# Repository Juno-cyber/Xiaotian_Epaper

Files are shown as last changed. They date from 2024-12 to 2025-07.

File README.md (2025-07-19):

# xiaotian_Epaper

**一款语音控制的墨水屏桌面助手**

**具备时间显示、倒计时事件显示、累积事件显示、语音控制功能**

**一款动动嘴就能交互的极简风桌面摆件！**

**组成：** 墨水屏、stm32、vc02语音模块、实时时钟

**使用软件：** cubeide1.16.1、lceda专业版、solidworks2024、keyshot2024

**<font color='RedOrange'>完整资料：</font>** **已上传**github-[Xiaotian_Epaper](https://github.com/Juno-cyber/Xiaotian_Epaper)，gitee-[Xiaotian_Epaper](https://gitee.com/Juno-cyber/Xiaotian_Epaper)，oshwhub-[电路设计](https://oshwhub.com/juno_eda/xiaoshi_epaper)

**<font color='RedOrange'>视频：</font>**[[开源]墨水屏桌面备忘录！](https://www.bilibili.com/video/BV1hEdBY6EPM/?vd_source=bac4ee29cb575aa9bf0947bee030705f)

**<font color='RedOrange'>BOM清单：</font>**`1.Hadware\BOM清单2024-12-14.xlsx`

**<font color='RedOrange'>更新日志：</font>** 

1. 2025.5.16：解决了偶然出现的秒计时超出60导致计时停止问题，优化了时间自动更新（若编译时间超前当前时间或当前时间大于编译时间20年则更新为编译时间）
1. 2025.4.13：添加scene3红黑显示demo，为”时间时加一“添加边界限制；更新了3D结构文件，删除了需要内嵌螺母的我外壳版本；pcb完善了丝印；
1. 2025.2.11：首次烧录时根据系统编译时间自动更新时钟芯片时间
1. 2025.1.18：更新bom表中黑白红墨水屏器件链接，更新程序，添加二次开发教程
1. 2025.1.5：添加pcb焊接建议，bom表中增加了我使用的下载器购买链接
1. 2024.12.28：添加黑白红墨水屏供选择，版本v0.0.2
1. 2024.12.13：首次上传，版本v0.0.1

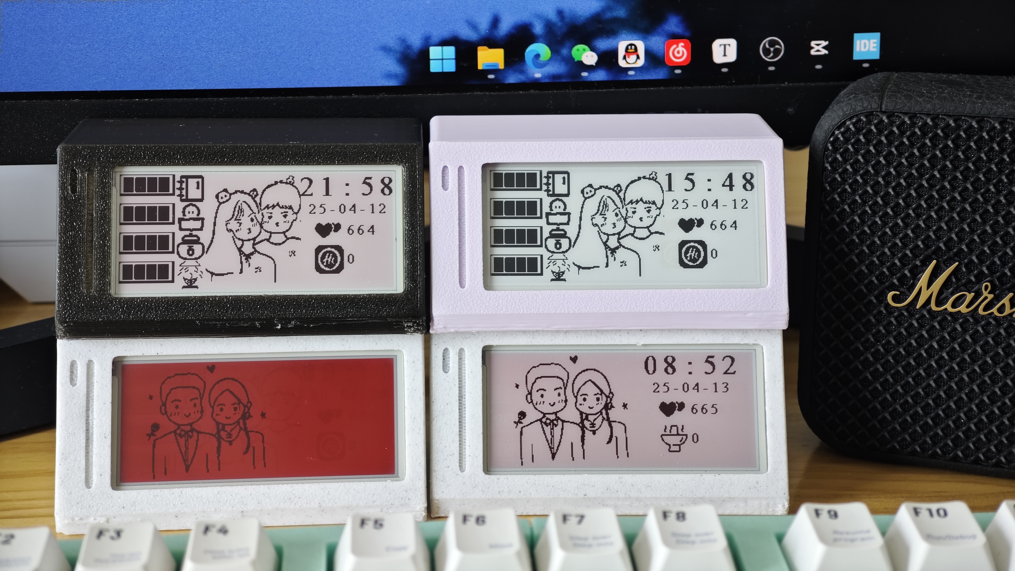
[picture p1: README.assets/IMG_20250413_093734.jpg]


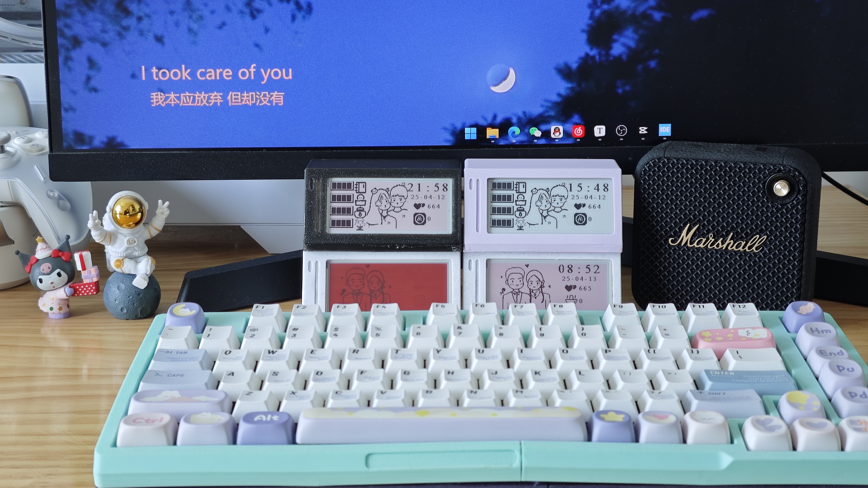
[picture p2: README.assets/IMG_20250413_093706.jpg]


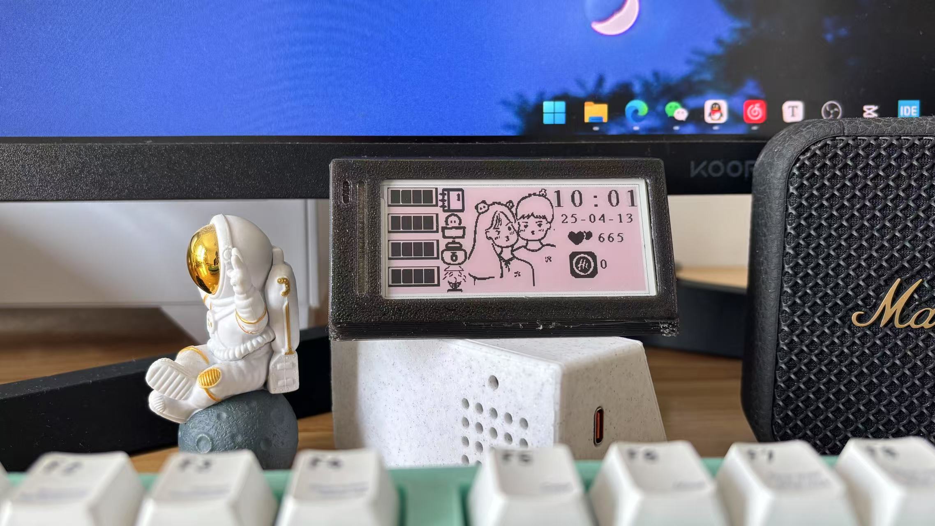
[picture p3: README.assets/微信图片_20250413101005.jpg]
微信图片_20250413101005


| 序号 | 文件名 | 描述 |
| ---- | --- | --- |
| 1 | Hardware | 硬件设计，BOM清单 |
| 2 | Firmware | 固件文件 |
| 3 | Software | 软件程序 |
| 4 | CAD_Model | 模型文件 |
| 5 | Docs | 文档 |
| 6 | Tools | 附带工具 |
| 7 | img | 输出图片 |
| 8 | REDME.assets | REDME中的图片 |

## 控制指令

**语音控制指令集**

| 命令词 | 回复语 | 备注 |
| --- | --- | --- |
| 请介绍你自己 | 你好我叫小天 我是一个桌面助手<br /> 你可以通过语音和我进行交互<br /> 你可以说浇过花了 浇过水了 更改时间 更换图片<br /> 有什么需要尽管给我说 | 需唤醒 |
| 你好小天\|小天小天 | 随时待命 | 唤醒词 |
| 写完日记了 | 记录每一天 | 需唤醒 |
| 看完书了 | 日拱一卒功不唐捐 | 需唤醒 |
| 加过水了 | 下次早点浇 | 需唤醒 |
| 坛子加过水了 | 美味需要时间酝酿 | 需唤醒 |
| 吃了海底捞 | 发工资了吗又吃海底捞 | 需唤醒 |
| 更改时间 | 想要调整时间你可以说时间年加一或者时间年减一 | 需唤醒 |
| 时间年加一 | | 需唤醒 |
| 时间年减一 | | 需唤醒 |
| 时间月加一 | | 需唤醒 |
| 时间月减一 | | 需唤醒 |
| 时间日加一 | | 需唤醒 |
| 时间日减一 | | 需唤醒 |
| 时间时加一 | | 需唤醒 |
| 时间时减一 | | 需唤醒 |
| 时间分加一 | | 需唤醒 |
| 时间分减一 | | 需唤醒 |
| 更换图片 | 已经更换照片 | 需唤醒 |

## 器件选型

**完整的bom清单在github和gitee工程中**：`Xiaotian_Epaper\1.Hadware\BOM清单2024-12-14.xlsx`

零件可在立创商城或者淘宝购买，哪里便宜在哪里买就好了

**墨水屏[Epaper](https://item.taobao.com/item.htm?id=520630517588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)：**

分辨率296x128像素 、2.9寸、黑白

刷新方式：全屏刷新/局部刷新（4灰阶不支持局刷）

刷新时间：全刷3秒，局刷0.6秒

据说无故障刷新次数为100w次，我设置每分钟刷新一次，那这样算，能够用两年，想想也还有点短

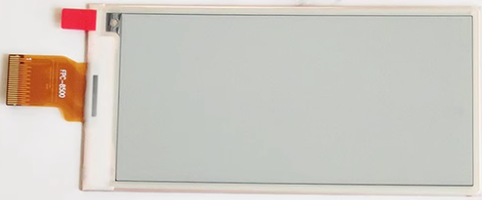
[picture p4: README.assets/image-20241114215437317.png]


**stm32f103cbt6**

72M主频，基本外设丰富，特别的是128k flash，对于当前所选墨水屏分辨率来说

一张全屏照片大小=296x128/8=4.7k，即使考虑到用上freeRTOS也可以无压力存20来张图像，并且往往无需全屏图像，对于个人开发来说完全够用了

**vc02语音模块**

一款低成本纯离线语音识别模组，**简单说就是写好对答语句，说特定语句执行特定功能**，这里使用时，说出特定语句发送串口指令到主控进行任务控制。支持150条本地指令离线识别，支持RTOS轻量级系统，具有丰富的外围接口，以及简单友好的[客制化工具](http://voice.ai-thinker.com/#/)，该项目放弃了按键交互，完全使用语音模块进行交互，**想干嘛动动嘴就行，君子动口不动手！**

**DS1302**

一款时钟芯片，用于离线时间记录，确保断电后设备仍然能保持时间

## 软件框架

使用cubeide经过初步封装后的freeRTOS，建立了四个任务init、show、run、read，分别执行初始化、显示、主要运行计算、读取任务

为了降低不同任务抢夺共享资源，用了两个无限时间等待的信号量确保run任务正常运行，用了两个事件组分别控制时钟芯片的数据读写和墨水屏的刷新显示

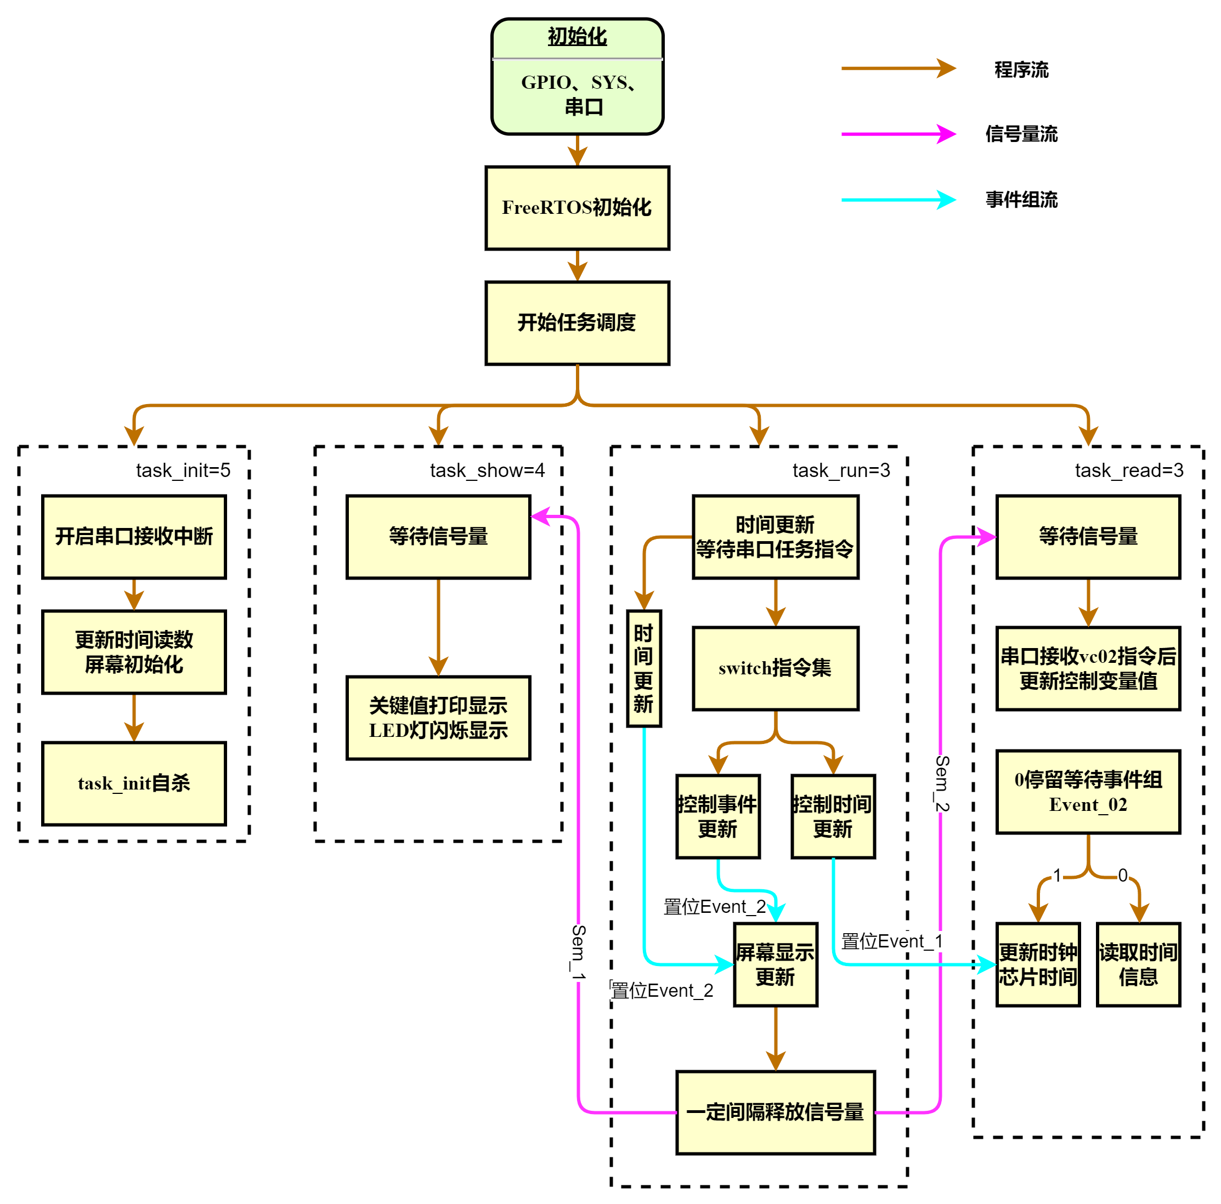
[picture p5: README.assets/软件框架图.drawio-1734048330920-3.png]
软件框架图.drawio


## 模块数据流

列出硬件组成中模块的电气连接及数据流向

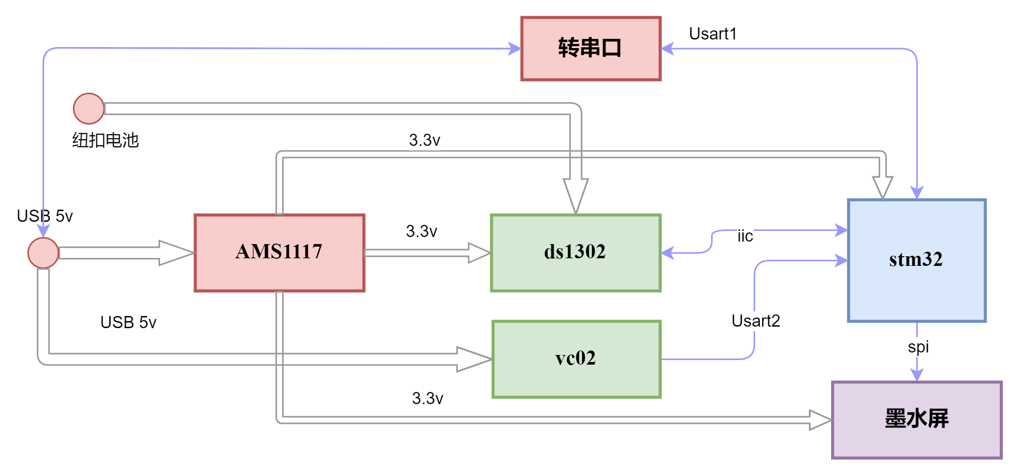
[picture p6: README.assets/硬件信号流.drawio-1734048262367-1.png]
硬件信号流.drawio


## 3D设计及安装

巧妙地外壳和屏幕壳体设计，使用Bambu的0.12mm打印刚好将屏幕壳体嵌入到外壳中，在底部使用两颗平头螺丝固定，表面外壳看不出什么安装的痕迹，对于审美的一点点强迫症，舒适了！

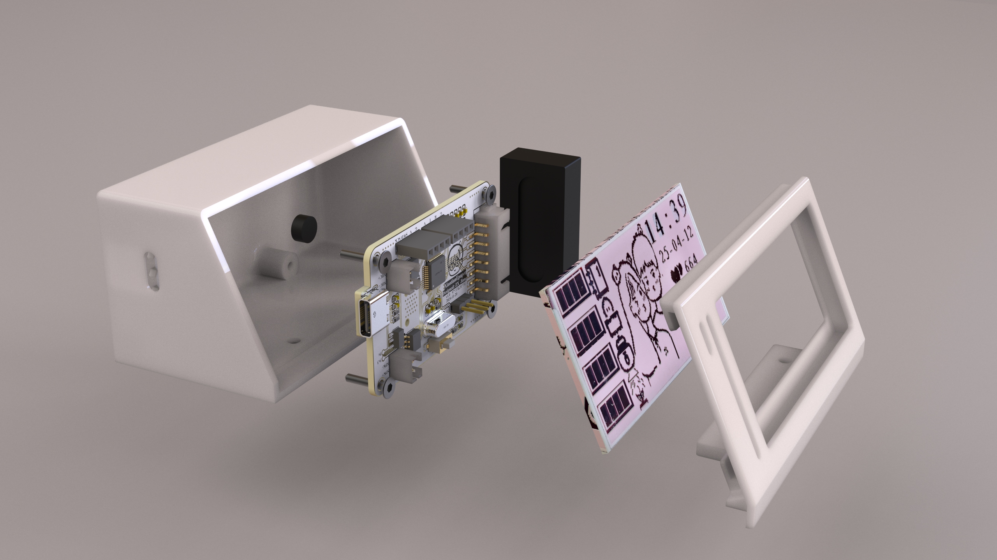
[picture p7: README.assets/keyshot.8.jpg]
keyshot.8


安装需要准备以下零件，选购链接已经在BOM表`Xiaotian_Epaper\1.Hadware\BOM清单2024-12-14.xlsx`中给出

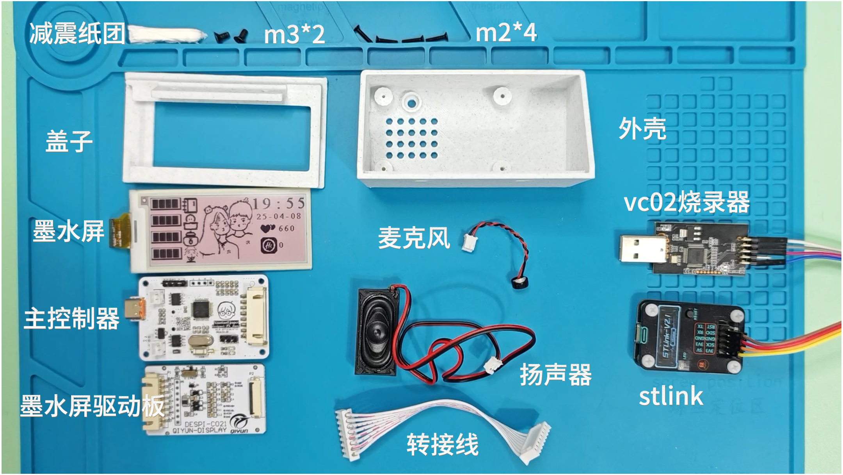
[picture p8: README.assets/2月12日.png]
2月12日


## PCB焊接建议

电容电阻使用的0603封装，需要用到**加热台**和**烙铁**，焊接不当需要拆除的话也需要用到**热风枪**，这里给一些手工焊接的建议，如果采用SMT焊接可以不用看

1. 手工焊接建议开钢网，当然想纯白嫖也可以不开，我没开也焊接成功了，就是难度稍微高一点
2. 首先用加热台焊接元器件最多的一面，但**注意不要一开始就把引脚密集的typeC和stm32主控芯片贴上去**，因为引脚过于密集，但凡锡膏多加一点就会短接，后续用烙铁不好分开，有的同学可能说用助焊剂容易分开，但我以前用的时候发现**助焊剂加热时间久了会导电短路**，有点恐怖。我实际发现比较好的方法是在加热台上等锡膏都融化了，用镊子把粘连的锡抚顺了，然后再放上typeC和stm32主控，成功率提高很多！
3. 焊接好了可以先连接typeC测试串口，能检测到串口一般说明最难的主控和typeC焊接没什么问题，有问题的话先检查用的线是不是只能充电没有信号线，确定是焊接问题，就需要用热风枪吹热拆下来然后再焊接了

**焊接成品如下**，手工抹的锡膏，表面会有一些锡球不那么美观

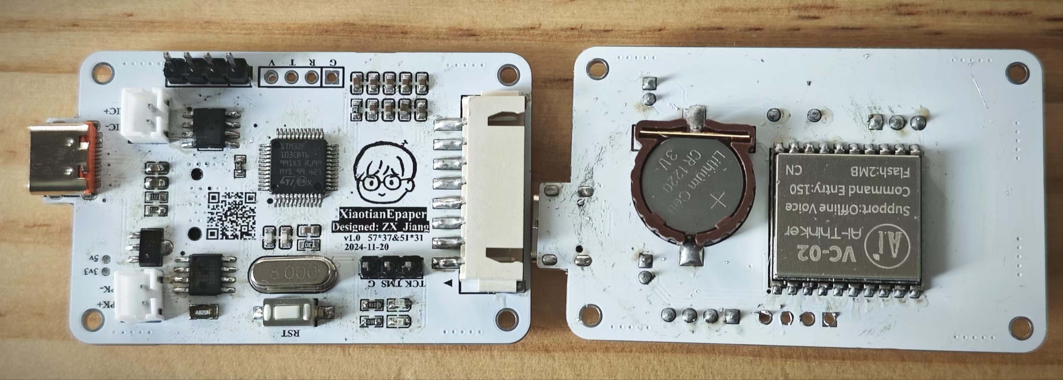
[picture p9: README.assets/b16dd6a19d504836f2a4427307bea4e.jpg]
b16dd6a19d504836f2a4427307bea4e


## 程序烧录

**<font color='RedOrange'>参考视频：</font>**[[开源]墨水屏桌面备忘录！](https://www.bilibili.com/video/BV1hEdBY6EPM/?vd_source=bac4ee29cb575aa9bf0947bee030705f)

## 二次开发教程

### 不同墨水屏选择

文件路径：`"Xiaotian_Epaper\3.Software\Xiaotian_Epaper\Libraries\include\EPAPER.h"`

```c
//选择屏幕类型，共适配了两种类型的显示屏，bom表中有列出链接，可以根据自己选择来做选择
#define black_white_red	//使用黑白红墨水屏
//#define black_white			//使用黑白墨水屏
```

### 自己创建新的场景（以主图为例）

1.定义场景名称，路径：`"Xiaotian_Epaper\3.Software\Xiaotian_Epaper\Libraries\include\myfreertos.h"`

```c
// 可以参考定义自己的场景
#define scene1						//显示场景1
//#define scene2						//显示场景2
```

2.在**init_show()**函数中初始化场景，路径`"Xiaotian_Epaper\3.Software\Xiaotian_Epaper\Libraries\mytasks\task_show.c"`

```
void init_show(){

	//****
	
#ifdef scene1
#ifdef black_white_red
	EPD_WhiteScreen_Black();
#else
	EPD_WhiteScreen_White();
#endif
	EPD_W21_Init();
	//white
	EPD_Dis_Part(0, 0, gImage1_white, 296, 128, NEG);
	//right
	EPD_Dis_string(186, 0, time, 32, NEG);
	EPD_Dis_string(200, 32, date, 16, NEG);
	EPD_Dis_Part(210, 48, gImage_love, 32, 32, POS);
	EPD_Dis_string(210 + 32, 56, itoa(date_diff(Time_start, Time_now),temp_itoa,10), 16, NEG);
	EPD_Dis_Part(210, 80, gImage_haidi, 32, 32, NEG);
	EPD_Dis_string(210 + 32, 88, itoa(date_diff(Time_haidilao, Time_now),temp_itoa,10), 16, NEG);
	//middle
	EPD_Dis_Part(85, 0, photo1, 110, 128, POS);
	//	left
	EPD_Dis_power(0, 0, (date_diff(event_power[0], Time_now)>4)?0:4-date_diff(event_power[0], Time_now));
	EPD_Dis_power(0, 32, (date_diff(event_power[1], Time_now)>4)?0:4-date_diff(event_power[1], Time_now));
	EPD_Dis_power(0, 64, (date_diff(event_power[2], Time_now)>4)?0:4-date_diff(event_power[2], Time_now));
	EPD_Dis_power(0, 96, (date_diff(event_power[3], Time_now)>4)?0:4-date_diff(event_power[3], Time_now));
	EPD_Dis_Part(60, 0, gImage_riji, 32, 32, NEG);
	EPD_Dis_Part(60, 32, gImage_dushu, 32, 32, POS);
	EPD_Dis_Part(60, 64, gImage_tanzi, 32, 32, POS);
	EPD_Dis_Part(60, 96, gImage_jiaoshui, 32, 32, POS);
#endif

	//****

}
```

3.在**update_show**()函数中定义更新逻辑，路径`"Xiaotian_Epaper\3.Software\Xiaotian_Epaper\Libraries\mytasks\task_show.c"`

图片数组在`"Xiaotian_Epaper\3.Software\Xiaotian_Epaper\Libraries\EPD_W21\EPAPER.c"`中定义，在`"Xiaotian_Epaper\3.Software\Xiaotian_Epaper\Libraries\include\EPAPER.h"`中使用`extern`命令进行外部声明，可参考现有图片数组更改

**注：图片数组取模具体操作参考后文中工具使用部分**

```c
void update_show()
{
    
	//****
	
#ifdef scene1
	//white
	EPD_Dis_Part(0, 0, gImage1_white, 296, 128, NEG);
	//right
	EPD_Dis_string(186, 0, time, 32, NEG);
	EPD_Dis_string(200, 32, date, 16, NEG);
	EPD_Dis_Part(210, 48, gImage_love, 32, 32, POS);
	EPD_Dis_string(210 + 32, 56, itoa(date_diff(Time_start, Time_now),temp_itoa,10), 16, NEG);
	EPD_Dis_Part(210, 80, gImage_haidi, 32, 32, NEG);
	EPD_Dis_string(210 + 32, 88, itoa(date_diff(Time_haidilao, Time_now),temp_itoa,10), 16, NEG);
	//middle
	EPD_Dis_Part(85, 0, photo1, 110, 128, POS);
	//	left
	EPD_Dis_power(0, 0, (date_diff(event_power[0], Time_now)>4)?0:4-date_diff(event_power[0], Time_now));
	EPD_Dis_power(0, 32, (date_diff(event_power[1], Time_now)>4)?0:4-date_diff(event_power[1], Time_now));
	EPD_Dis_power(0, 64, (date_diff(event_power[2], Time_now)>4)?0:4-date_diff(event_power[2], Time_now));
	EPD_Dis_power(0, 96, (date_diff(event_power[3], Time_now)>4)?0:4-date_diff(event_power[3], Time_now));
	EPD_Dis_Part(60, 0, gImage_riji, 32, 32, NEG);
	EPD_Dis_Part(60, 32, gImage_dushu, 32, 32, POS);
	EPD_Dis_Part(60, 64, gImage_tanzi, 32, 32, POS);
	EPD_Dis_Part(60, 96, gImage_jiaoshui, 32, 32, POS);
#endif

	//****

}
```

### 语音控制指令自定义

vc02的语音控制可以在[安信可平台](http://voice.ai-thinker.com/#/YzsM)进行编辑并生成固件，每条控制指令对应有一个串口发送动作，编辑功能还需要再stm32源码中对应修改

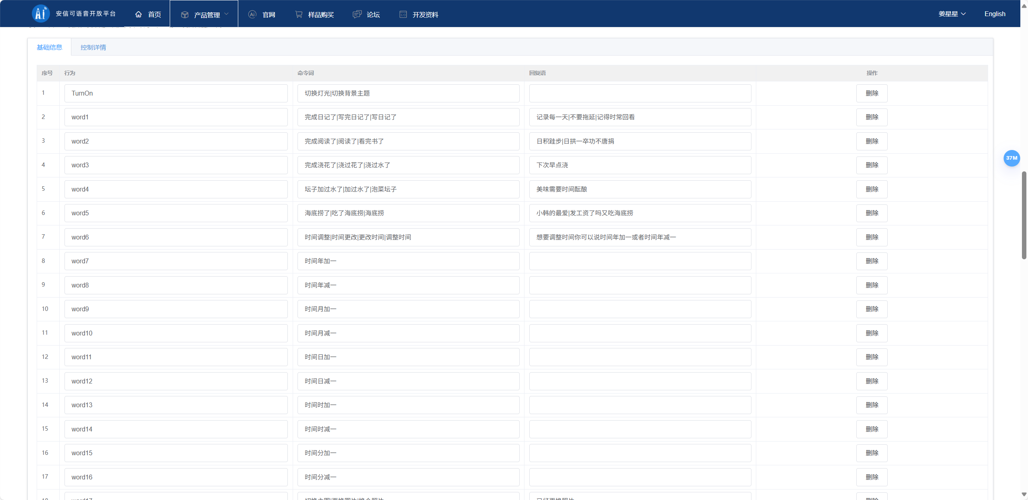
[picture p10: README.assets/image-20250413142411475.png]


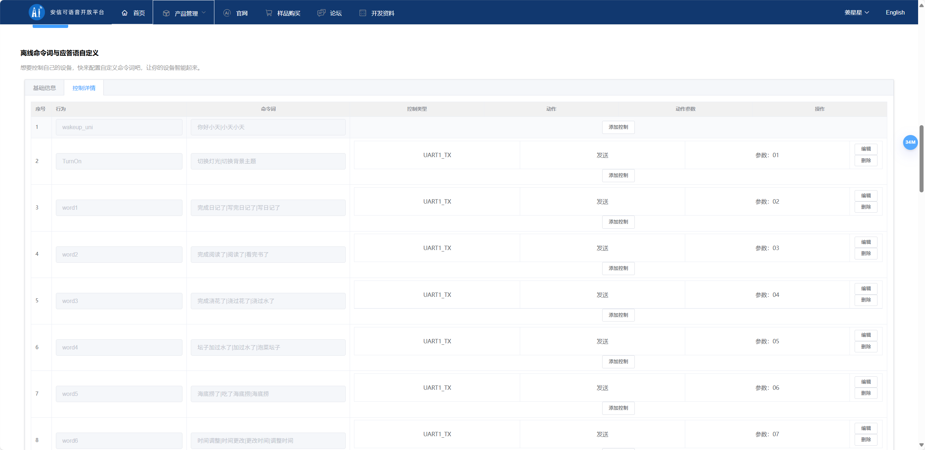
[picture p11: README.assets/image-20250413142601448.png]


## 工具使用

**1.使用取模软件制作图片数组**

首先了解2.9寸墨水屏显示尺寸为296*128，x方向可按1像素平移，**而y方向只能按8像素平移**（例如设置y=0，实际y=0；设置y=1~7，实际y=7）。以封面为例，主图大小为100x128px，所有小图标为32x32px，二次开发可参考该大小进行布局

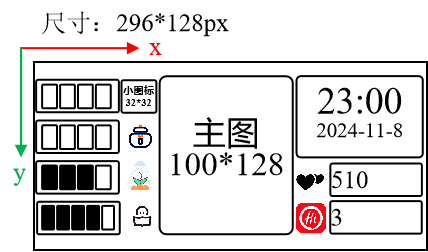
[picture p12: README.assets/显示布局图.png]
显示布局图


取模工具路径：`xiaotian_Epaper\6.Tools\CharacterMatrix 3.0.2.3.exe`

由于厂家给的墨水屏demo是按照x方向排列的，现在需要以y方向排列，因此需要按照以下步骤对图片进行**镜像和旋转**

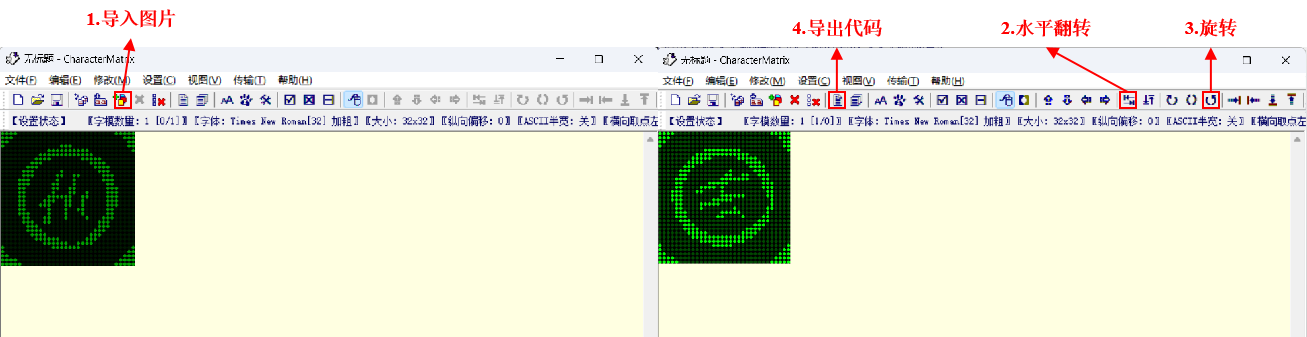
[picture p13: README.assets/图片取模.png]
图片取模


得到字模二进制数据后拷贝到文件对应位置即可

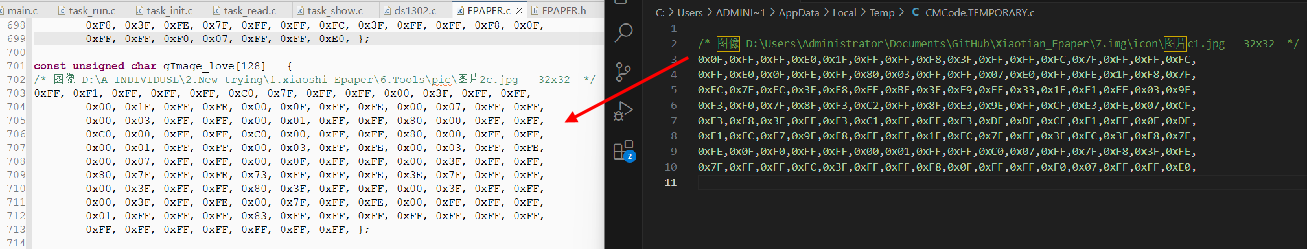
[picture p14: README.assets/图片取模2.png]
图片取模2


**2.vc02烧录工具**：[教程参考](https://blog.csdn.net/Boantong_/article/details/123846788)

专用下载工具路径（文件夹内有使用说明pdf）：`xiaotian_Epaper\6.Tools\hummingbird-m-production-tool\UniOneDownloadTool.exe`

串口烧录工具（测试没下载成功）：`Xiaotian_Epaper\6.Tools\hummingbird-m-update-tool\UniOneUpdateTool.exe`

固件路径：`xiaotian_Epaper\2.Firmware\uni_app_release.bin`

**3.串口助手**：`Xiaotian_Epaper\6.Tools\sscom\sscom5.13.1.exe`

## 字模压缩

### 游程编码压缩字模大小

考虑到嵌入式设备的flash容量有限，对保存的ASCII字模进行一定压缩处理，大大缩减了字模数组所占存储

取模软件取到的字模如下，在进行存储时，黑色区域存储为0x00，那么字模中就有大片的0x00存在，那么你一定能想到一种简单的思路对字模进行压缩。

如“0000000000”=”10个0“，这个思路叫做**游程编码**，其核心思想是通过减少重复数据的存储来实现压缩。在数据序列中，连续出现的相同元素组成的一段被称为一个“游程”。编码时，每个游程被替换为一个表示游程长度和游程值的二元组。例如，在字符串“AAAABBBCCDAA”中，“AAAA”是一个游程，长度为4，可以表示为(4, 'A')。

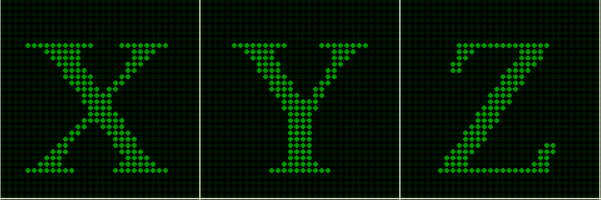
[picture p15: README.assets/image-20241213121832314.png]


**1.num-char压缩方式**

“AAAABBBCCDAA” =》 (4, 'A')(3, 'B')(2, 'C')(1, 'D')(2, 'A')

这种方式的压缩率**大概是81.89%**

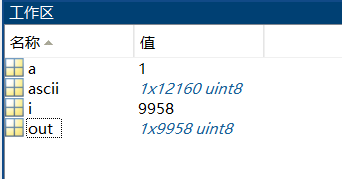
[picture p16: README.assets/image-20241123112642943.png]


**2.只压缩0x00的方式**

“00000AAAABBBCCDAA” =》 (5, 0x00)"AAAABBBCCDAA"

这种方式压缩率达到**51.19%**，**不过对应的编码和解码就麻烦一点**，这里自己写了一个`xiaotian_Epaper\6.Tools\ed_codem.m`文件进行处理，**项目也采用该方式进行字模压缩**

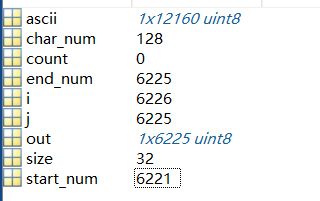
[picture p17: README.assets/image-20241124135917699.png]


**字模制作过程：**

先在字模工具中制作完成->生成.c文件用vscode打开->正则表达式进行替换，删除不必要的注释内容，替换成可输入到matlab中的形式->拷贝到ed_codem.m文件中进行运算->拷贝到c程序中

**字模数据处理所用正则表达式：**

```
/\*.*?\*/			搜索所有/*  */括起来的内容 
,(?![^,]*,)			选中所有行最后一个逗号
\n{2}				选中连续的两个换行符
```

## 最后

难度不是很高的一个项目，想锻炼一下贴片焊接、学习stm32设计开发、freeRTOS的同学都可以来试试，我会持续完善更新，期待大家交作业！

## 常见问题

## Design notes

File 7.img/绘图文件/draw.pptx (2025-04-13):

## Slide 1

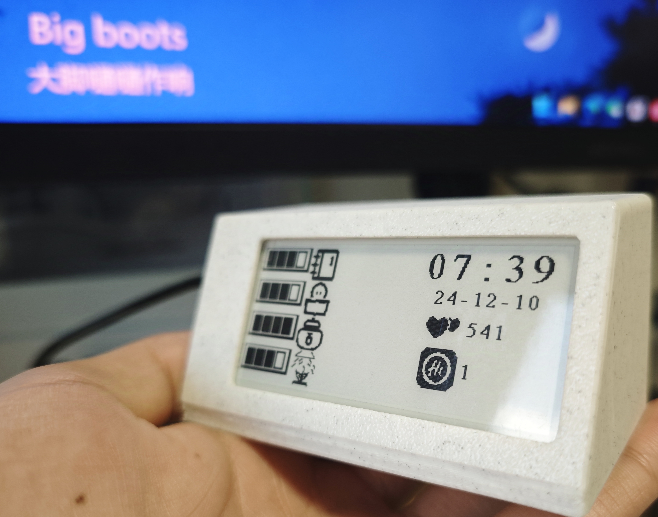
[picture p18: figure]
xiaotian

尺寸：296*128px

x

y

小图标
32*32

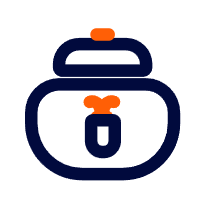
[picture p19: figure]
泡菜
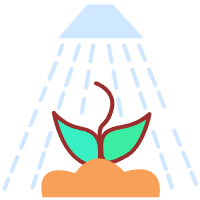
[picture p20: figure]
浇水

主图
100*128

23:00
2024-11-8

510

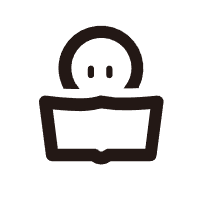
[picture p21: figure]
读书
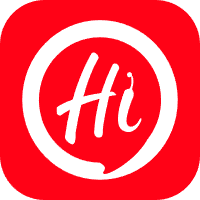
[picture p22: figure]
海底捞logo_支付宝生活号
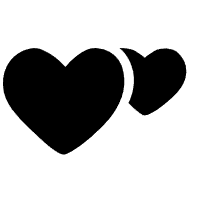
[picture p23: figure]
可爱的

3

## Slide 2

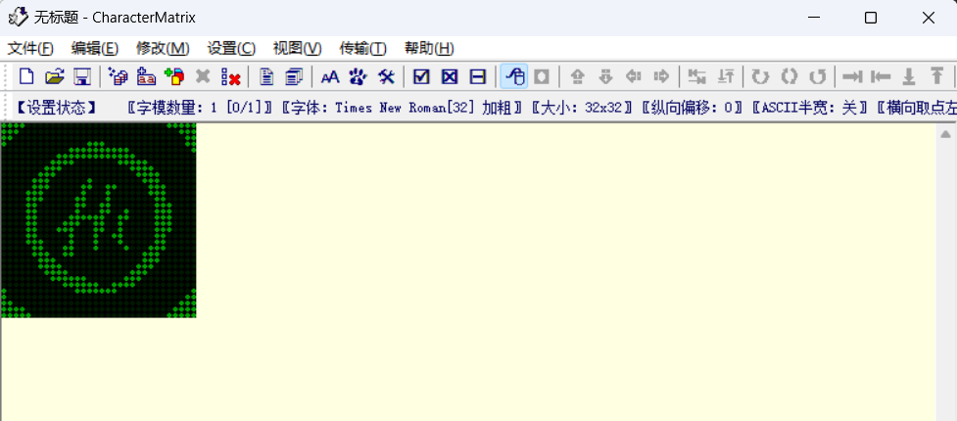
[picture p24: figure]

1.导入图片

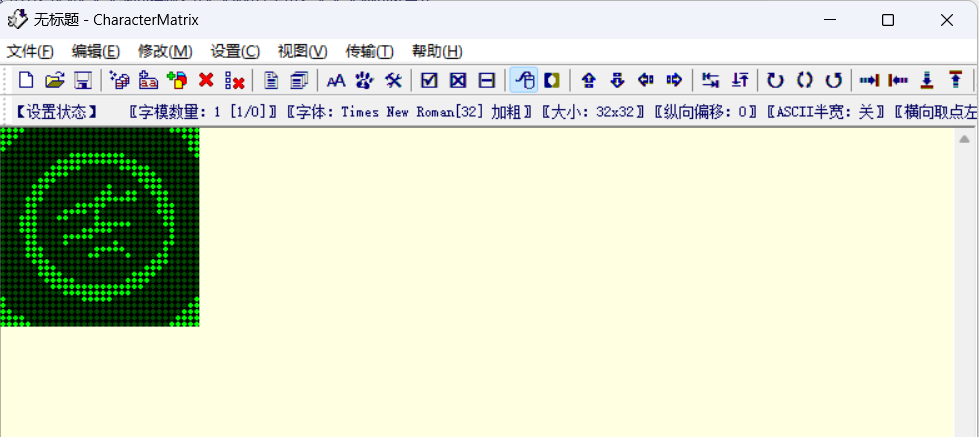
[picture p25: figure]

4.导出代码

2.水平翻转

3.旋转

1.导入图片

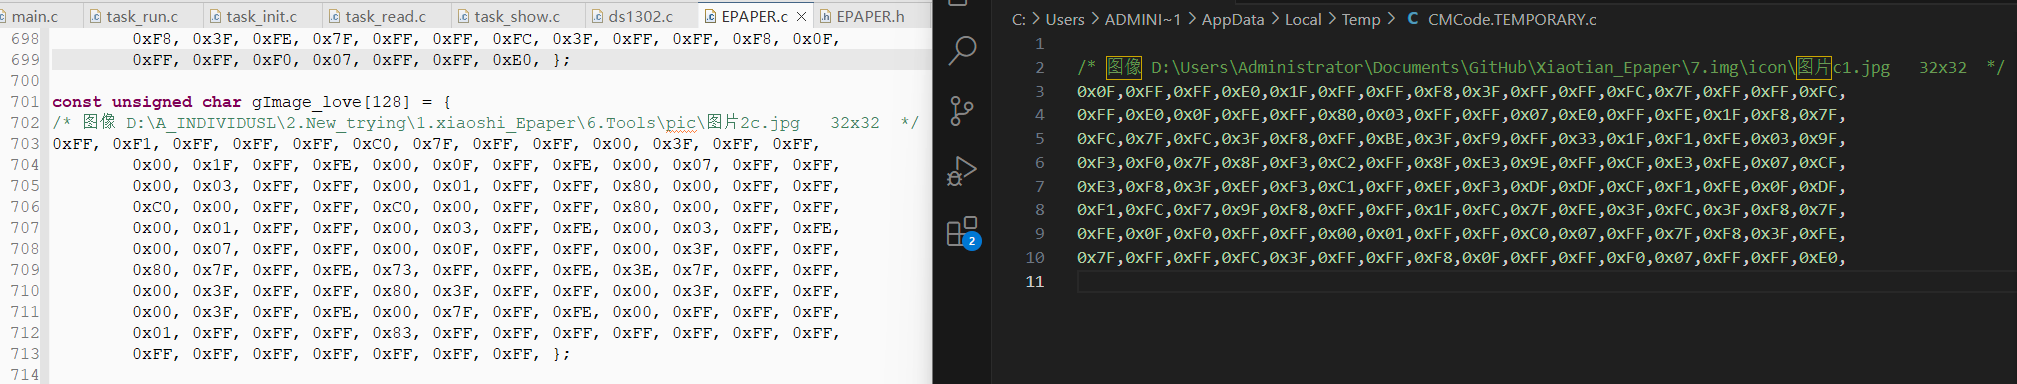
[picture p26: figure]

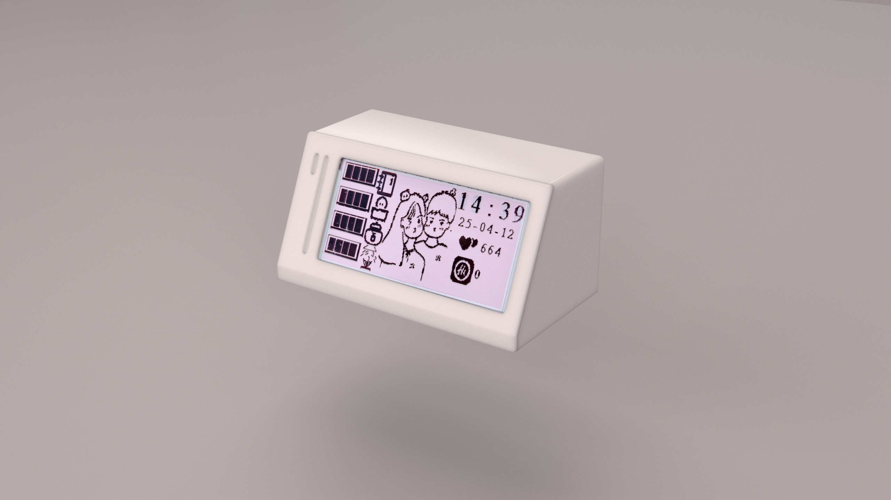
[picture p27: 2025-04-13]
7.img/展示图/keyshot.12.jpg

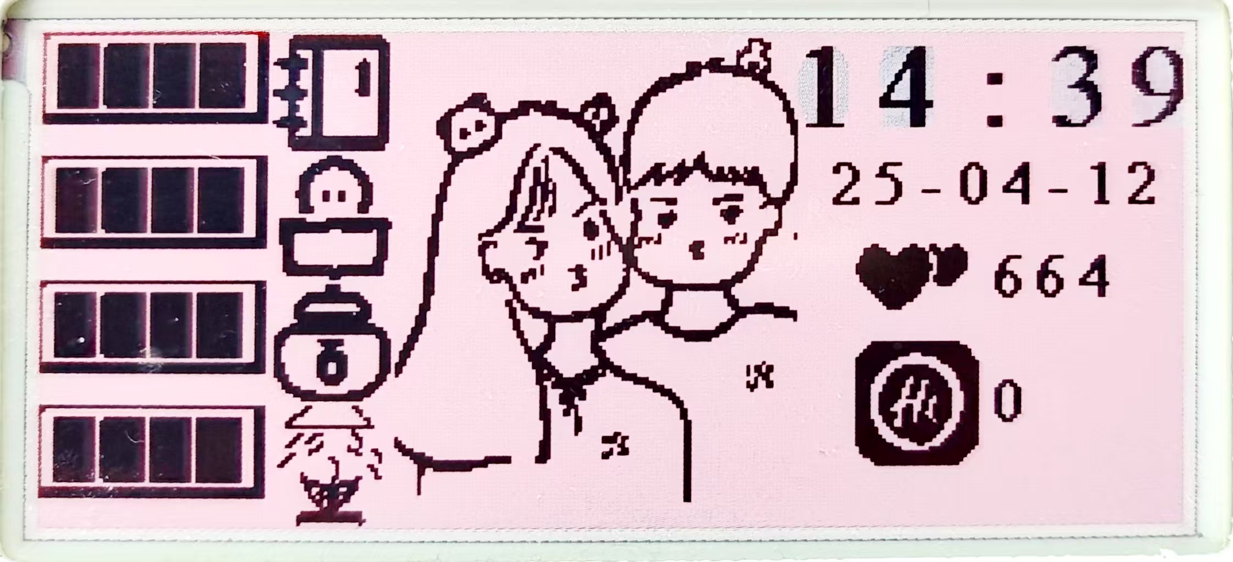
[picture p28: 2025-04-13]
4.CAD_Model/texture/封面1.jpg

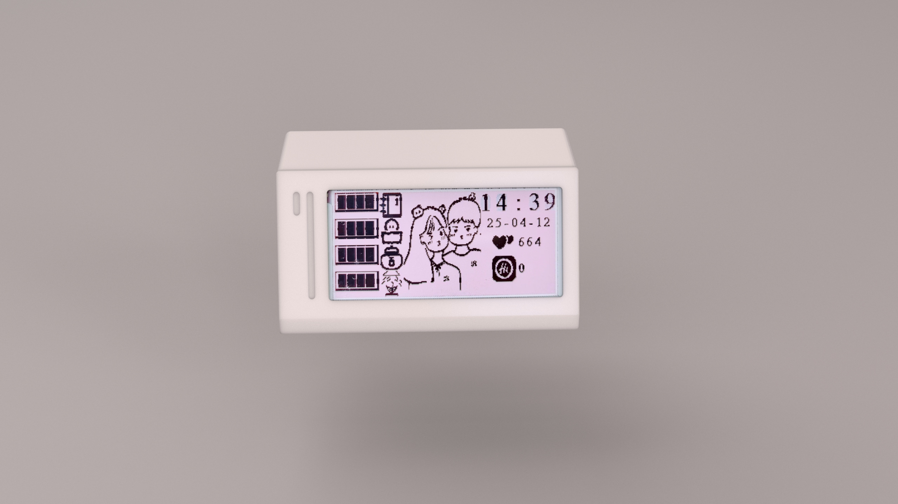
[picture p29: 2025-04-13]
7.img/展示图/keyshot.11.jpg

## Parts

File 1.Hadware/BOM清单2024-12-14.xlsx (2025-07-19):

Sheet: bom模板
 |  |  |  |  | Bill of Materials | BOM_Board1_Schematic1_2024-12-14
 |  |  |  |  | Project Title： | 极简风语音控制墨水屏桌面摆件【STM32 FreeRTOS】
 |  |  |  |  | Variant:
 |  |  |  |  | Report Time： | 2024年12月14日 13:29:31
 | No. | Quantity | Comment | Designator | Footprint | Value | Manufacturer Part | Manufacturer | Supplier Part
PCB元器件 | 1 | 1 | BS-12-B3AA009-R | BAT1 | BAT-SMD_BS-12-B3AA011 |  | BS-12-B3AA009-R | MYOUNG(美阳) | C964728
 | 2 | 2 | 10uF | C1, C8 | C0603 | 10uF | CL10A106KP8NNNC | SAMSUNG(三星) | C19702
 | 3 | 8 | 100nF | C2, C3, C4, C5, C7, C10, C12, C13 | C0603 | 100nF | CC0603KRX7R9BB104 | YAGEO(国巨) | C14663
 | 4 | 1 | 1uF | C6 | C0603 | 1uF | CL10A105KB8NNNC | SAMSUNG(三星) | C15849
 | 5 | 1 | 22uF | C9 | C0603 | 22uF | CGA0603X5R226M160JT | HRE(芯声) | C6119868
 | 6 | 2 | 20pF | C11, C14 | C0603 | 20pF | CL10C200JB8NNNC | SAMSUNG(三星) | C1648
 | 7 | 1 | 2.54-8P WT | CN1 | CONN-SMD_8P-P2.50_2.54-8P-WT |  | 2.54-8P WT | SHOU HAN(首韩) | C5340837
 | 8 | 1 | 2.54-1*3 | H1 | HDR-TH_3P-P2.54-V-M-1 |  | 2.54-1*3 | ZHOURI(洲日) | C5116482
 | 9 | 2 | PM2.54-1*4 | H2, H3 | HDR-TH_4P-P2.54-V-F |  | PM2.54-1*4 | ZHOURI(洲日) | C5116530
 | 10 | 2 | KT-0603R | LED1, LED2 | LED0603-RD |  | KT-0603R | KENTO | C2286
 | 11 | 2 | 5.1kΩ | R1, R2 | R0603 | 5.1kΩ | 0603WAF5101T5E | UNI-ROYAL(厚声) | C23186
 | 12 | 2 | 1kΩ | R3, R5 | R0603 | 1kΩ | 0603WAF1001T5E | UNI-ROYAL(厚声) | C21190
 | 13 | 3 | 10kΩ | R4, R6, R7 | R0603 | 10kΩ | 0603WAF1002T5E | UNI-ROYAL(厚声) | C25804
 | 14 | 1 | TS-1101-C-W | SW1 | SW-SMD_L6.0-W3.3-LS8.0 |  | TS-1101-C-W | XKB Connectivity(中国星坤) | C318938
 | 15 | 1 | STM32F103CBT6 | U1 | LQFP-48_L7.0-W7.0-P0.50-LS9.0-BL |  | STM32F103CBT6 | ST(意法半导体) | C8304
 | 16 | 1 | VC-02_CN | U2 | COMM-SMD_VC-02_CN |  | VC-02_CN | Ai-Thinker(安信可) | C3039677 | https://item.taobao.com/item.htm?_u=e1ttkhjhd2ba&id=675536394889&skuId=5069816756536
 | 17 | 1 | AMS1117-3.3 | U3 | SOT-89-3_L4.5-W2.5-P1.50-LS4.2-BR |  | AMS1117-3.3 | Slkor(萨科微) | C880752
 | 18 | 1 | CH340N | U4 | SOP-8_L4.9-W3.9-P1.27-LS6.0-BL |  | CH340N | WCH(南京沁恒) | C2977777
 | 19 | 1 | DS1302Z+T&R | U5 | SOIC-8_L4.9-W3.9-P1.27-LS6.0-BL |  | DS1302Z+T&R | ADI(亚德诺)/MAXIM(美信) | C8959
 | 20 | 2 | PH2.0D-L-2P | U6, U7 | CONN-TH_PH-2A_C2908623 |  | PH2.0D-L-2P |  | C2935791
 | 21 | 1 | KH-TYPE-C-16P | USB1 | USB-C-SMD_KH-TYPE-C-16P |  | KH-TYPE-C-16P | kinghelm(金航标) | C709357
 | 22 | 1 | 32.768kHz | X1 | FC-135R_L3.2-W1.5 | 32.768kHz | Q13FC13500004 | EPSON(爱普生) | C32346
 | 23 | 1 | 8MHz | X2 | OSC-TH_L10.0-W4.5-P5.00 | 8MHz | X49SD8MSD2SC | YXC(扬兴晶振) | C21263
额外零件 | 24 | 1 | 二选一就好了 |  |  | 2.9寸 | 墨水屏（黑白）+驱动板 |  |  | https://item.taobao.com/item.htm?from=cart&id=520630517588&skuId=3863425440922
 | 25 | 1 |  |  |  | 2.9寸 | 墨水屏（黑白红）+驱动板 |  |  | https://item.taobao.com/item.htm?_u=i1ttkhjh04ca&id=520811872543&sku_properties=5919063%3A6536025
 | 26 | 4 |  |  |  | M2*10 | 沉头内六角螺丝 (https://item.taobao.com/item.htm?id=617471305504&_u=e1ttkhjh0984)
 | 27 | 2 |  |  |  | M3*6 | 沉头内六角螺丝 (https://item.taobao.com/item.htm?id=617471305504&_u=e1ttkhjh0984)
 | 28 | 1 |  |  |  |  | VC-02-Kit配件-腔体喇叭 |  |  | https://item.taobao.com/item.htm?from=cart&id=674933692290&skuId=5041931059561
 | 29 | 1 |  |  |  |  | VC-02-Kit配件-咪头 |  |  | https://item.taobao.com/item.htm?from=cart&id=674933692290&skuId=5041931059560
 | 30 | 1 | VC-02下载调试器 |  |  |  | VC-02下载调试器 |  |  | https://item.taobao.com/item.htm?_u=51ttkhjh0060&id=674933692290&skuId=5038806030195
 | 31 | 1 | STM32下载调试器 |  |  |  | STM32下载调试器(调试器有多种，按需选择) |  |  | https://item.taobao.com/item.htm?_u=51ttkhjh09ae&id=693344222510&skuId=5091822046375
3D打印 | 32 | 1 | 小天-外壳.STL
 | 33 | 1 | 小天-盖子.STL

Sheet: Field汇总
Project Title | 极简风语音控制墨水屏桌面摆件【STM32 FreeRTOS】
Borard Title | Board1
Schematic Title | Schematic1
PCB Title
Variant Name
Total Quantity | 39
Report Time | 13:29:31
Report Date | 2024年12月14日
Report Date&Time | 2024年12月14日 13:29:31
File Name | BOM_Board1_Schematic1_2024-12-14
Filter Option | Add into BOM:no;

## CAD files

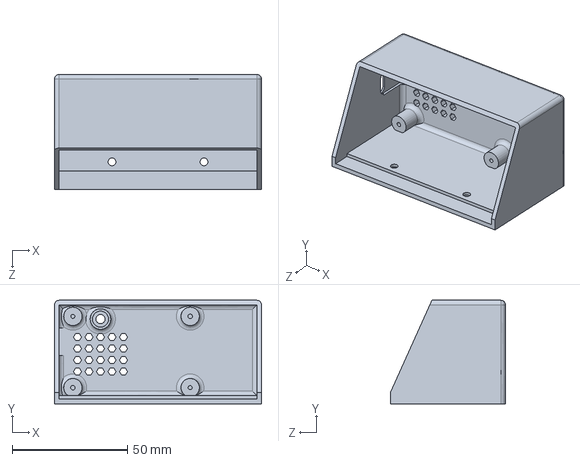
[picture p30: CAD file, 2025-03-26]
4.CAD_Model/外壳1.SLDPRT
90.0 x 45.0 x 50.0 mm

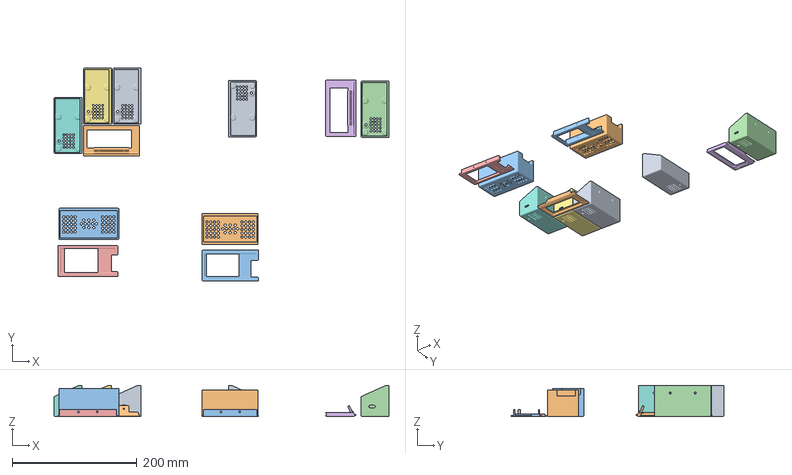
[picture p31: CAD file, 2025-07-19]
4.CAD_Model/打印/拓竹打印工程.3mf
536.7 x 341.1 x 50.0 mm
外壳1.STL x 4
小智外壳.STL x 2
外壳1 - 无内嵌螺母版本.STL
小智盖子.STL x 2
盖子.STL x 2

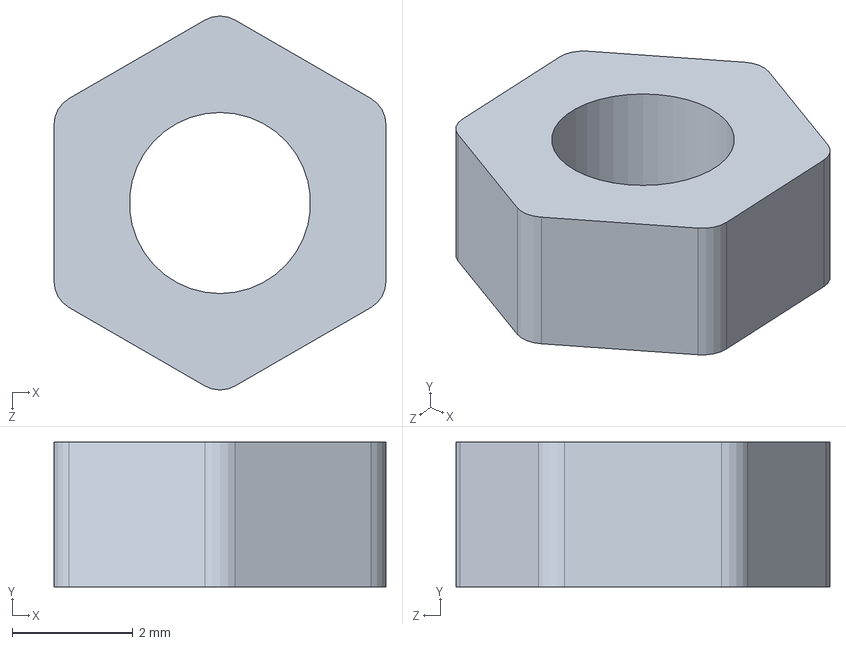
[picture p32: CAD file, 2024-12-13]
4.CAD_Model/m3螺母.SLDPRT
5.50 x 2.40 x 6.20 mm

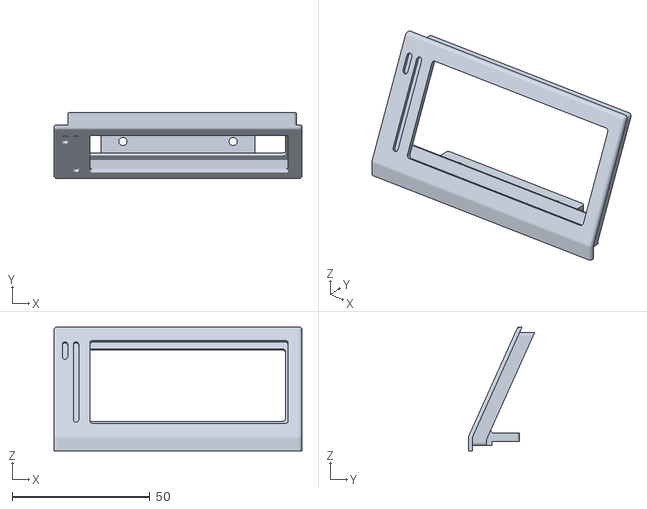
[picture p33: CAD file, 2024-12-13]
4.CAD_Model/打印/小天-盖子.STL
90.0 x 24.1 x 45.0

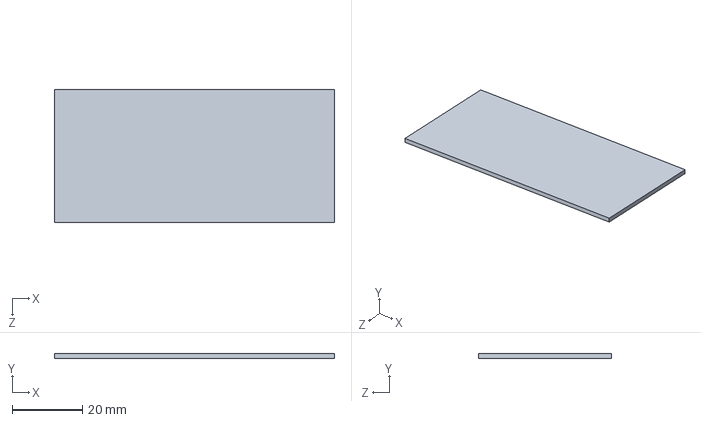
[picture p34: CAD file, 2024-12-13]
4.CAD_Model/显示屏.SLDPRT
80.0 x 1.40 x 38.0 mm

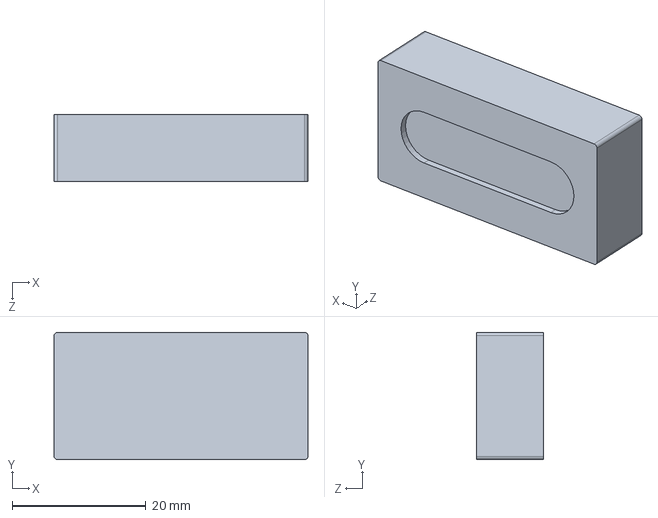
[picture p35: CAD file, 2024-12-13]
4.CAD_Model/喇叭.SLDPRT
38.0 x 19.0 x 10.0 mm

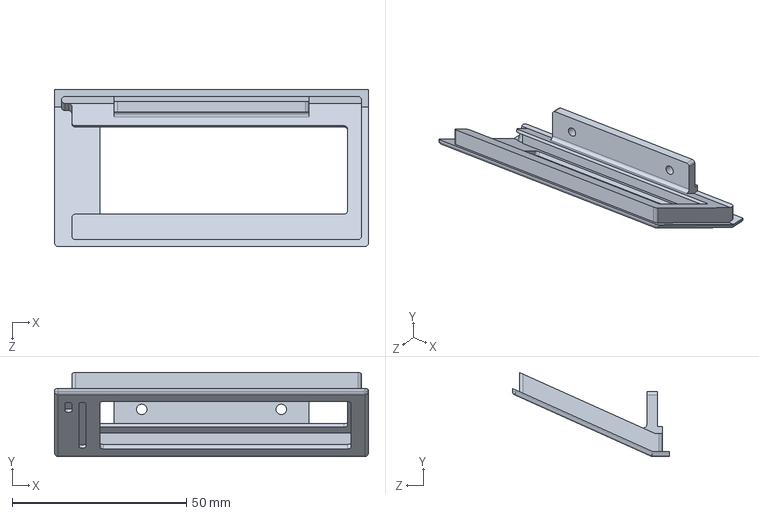
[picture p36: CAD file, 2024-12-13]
4.CAD_Model/盖子.SLDPRT
90.0 x 24.1 x 45.0 mm

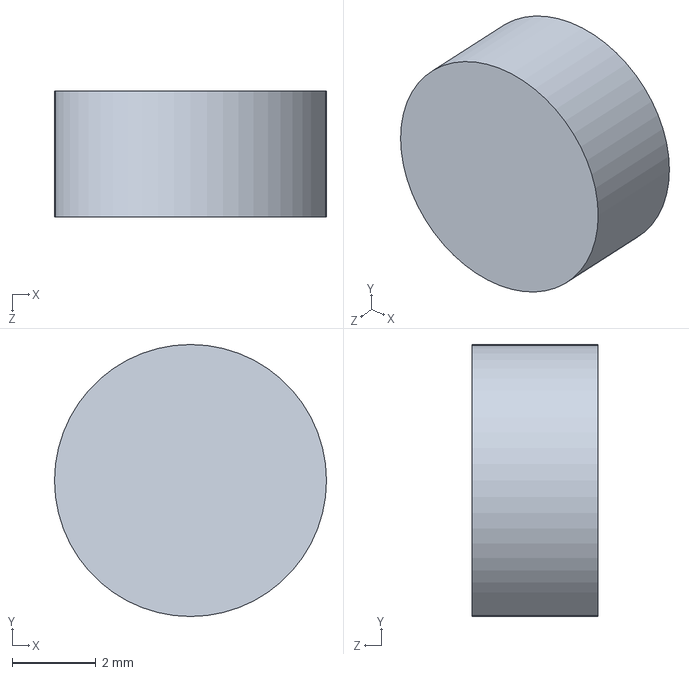
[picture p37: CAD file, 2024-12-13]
4.CAD_Model/麦克风.SLDPRT
6.50 x 6.50 x 3.00 mm

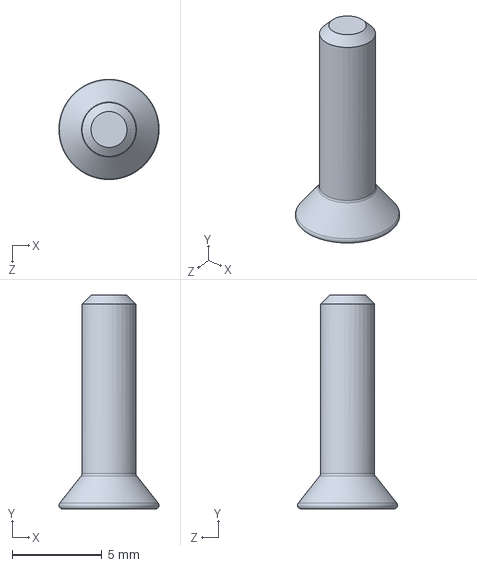
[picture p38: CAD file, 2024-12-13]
4.CAD_Model/M3-10mm.SLDPRT
5.57 x 11.9 x 5.57 mm

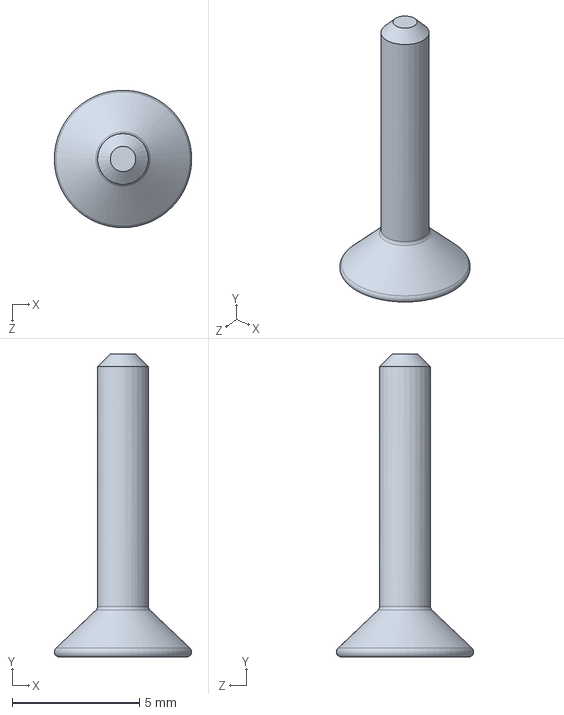
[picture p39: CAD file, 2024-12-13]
4.CAD_Model/M2-10mm.SLDPRT
5.39 x 11.9 x 5.39 mm

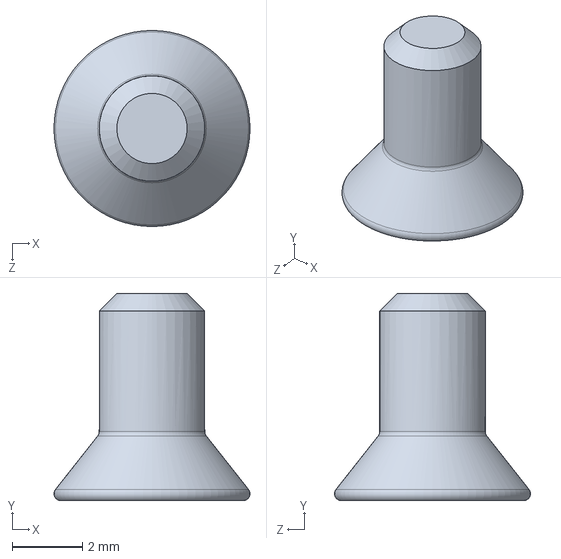
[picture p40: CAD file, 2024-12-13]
4.CAD_Model/M3-6mm.SLDPRT
5.57 x 5.90 x 5.57 mm

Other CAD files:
4.CAD_Model/打印/小天-外壳.STL

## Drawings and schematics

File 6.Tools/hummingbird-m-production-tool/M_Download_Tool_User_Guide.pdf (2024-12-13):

# 蜂鸟 M 芯片方案

# 烧录工具使用指南 v1.1

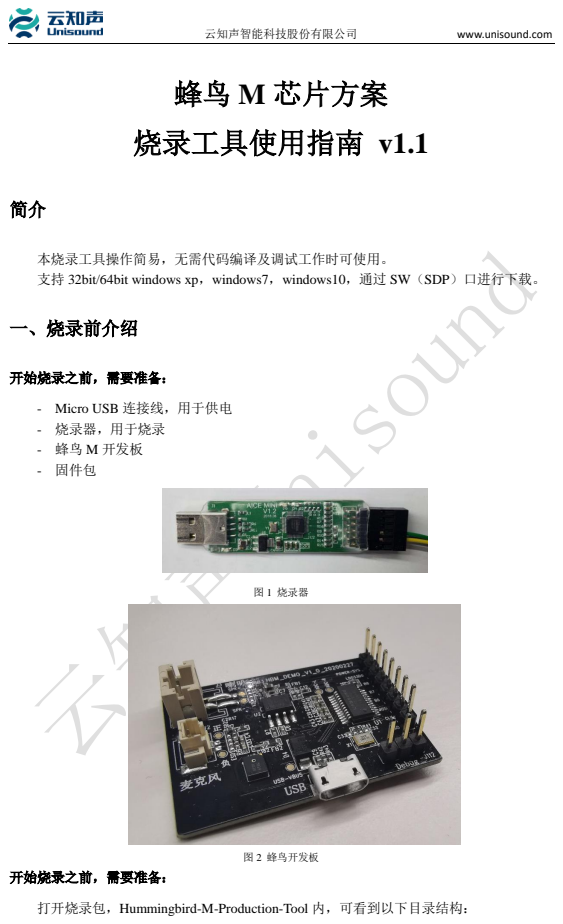
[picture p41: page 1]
云知声智能科技股份有限公司; www.unisound.com; 一、烧录前介绍; 开始烧录之前，需要准备：; 图 1 烧录器; 图 2 蜂鸟开发板

本烧录工具操作简易，无需代码编译及调试工作时可使用。
支持 32bit/64bit windows xp，windows7，windows10，通过 SW（SDP）口进行下载。

- Micro USB 连接线，用于供电
- 烧录器，用于烧录
- 蜂鸟 M 开发板
- 固件包

打开烧录包，Hummingbird-M-Production-Tool 内，可看到以下目录结构：

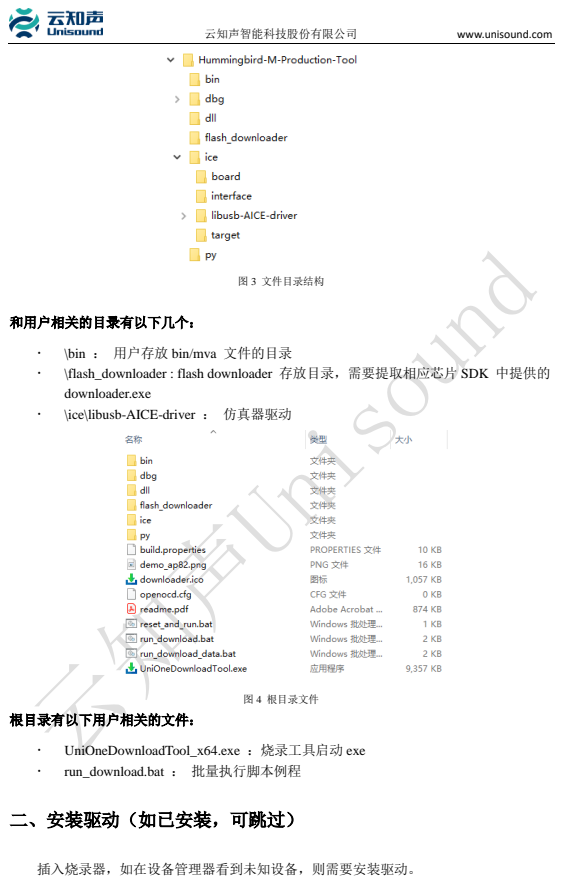
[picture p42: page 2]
图 3 文件目录结构; 和用户相关的目录有以下几个：; 图 4 根目录文件; 根目录有以下用户相关的文件：

\bin ： 用户存放 bin/mva 文件的目录
\flash_downloader : flash downloader 存放目录，需要提取相应芯片 SDK 中提供的
downloader.exe
\ice\libusb-AICE-driver ： 仿真器驱动

UniOneDownloadTool_x64.exe ：烧录工具启动 exe
run_download.bat ： 批量执行脚本例程

二、安装驱动（如已安装，可跳过）

插入烧录器，如在设备管理器看到未知设备，则需要安装驱动。

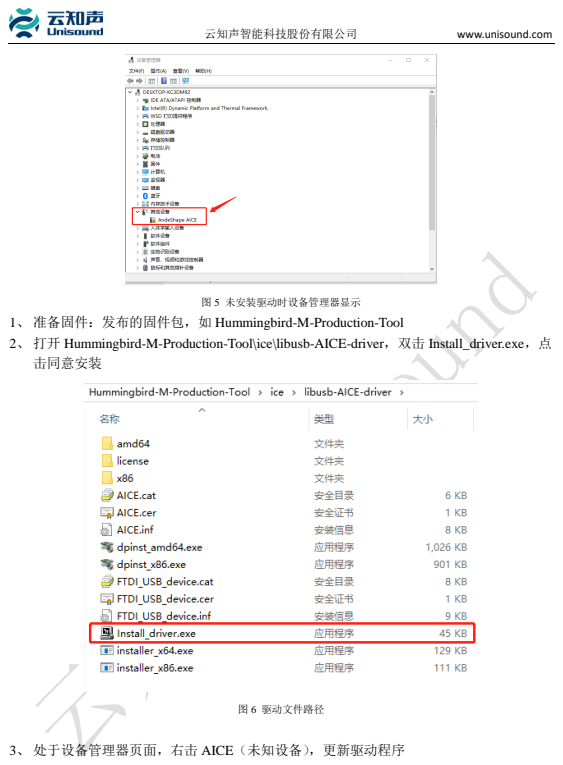
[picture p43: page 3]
图 5 未安装驱动时设备管理器显示; 图 6 驱动文件路径

1、 准备固件：发布的固件包，如 Hummingbird-M-Production-Tool
2、 打开 Hummingbird-M-Production-Tool\ice\libusb-AICE-driver，双击 Install_driver.exe，点
击同意安装

3、 处于设备管理器页面，右击 AICE（未知设备），更新驱动程序

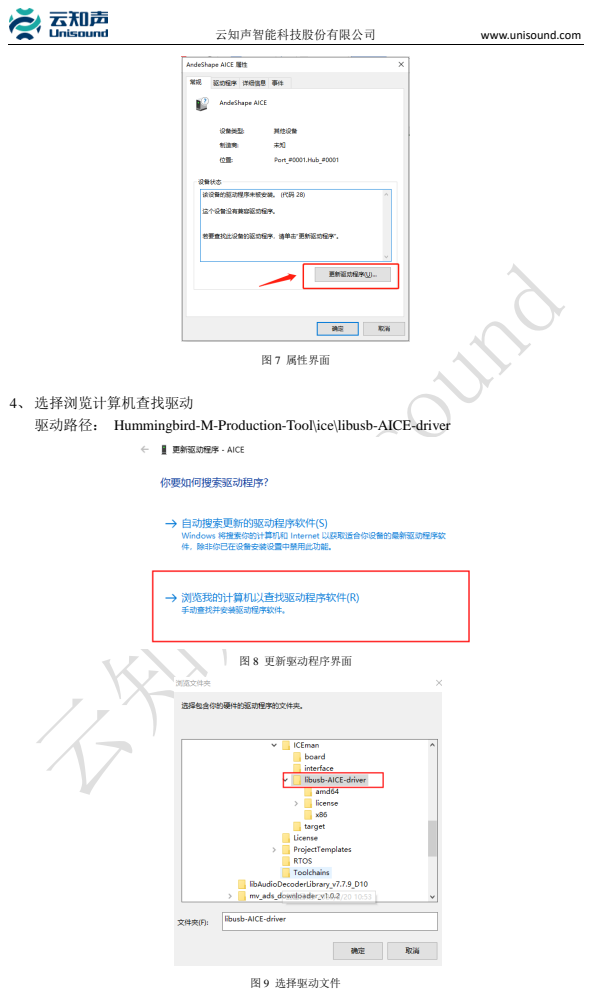
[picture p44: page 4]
图 7 属性界面; 图 8 更新驱动程序界面; 图 9 选择驱动文件

4、 选择浏览计算机查找驱动
驱动路径： Hummingbird-M-Production-Tool\ice\libusb-AICE-driver

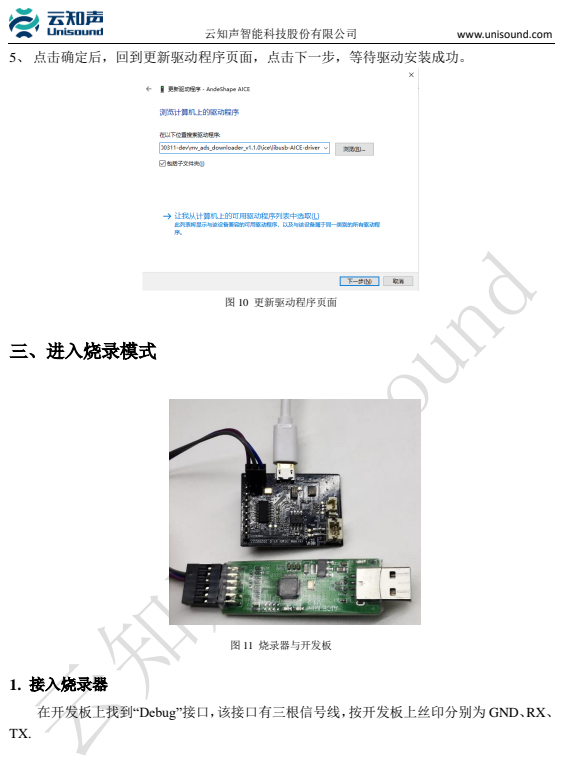
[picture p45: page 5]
图 10 更新驱动程序页面; 三、进入烧录模式; 图 11 烧录器与开发板; 1. 接入烧录器

5、 点击确定后，回到更新驱动程序页面，点击下一步，等待驱动安装成功。

在开发板上找到“Debug”接口，该接口有三根信号线，按开发板上丝印分别为 GND、RX、

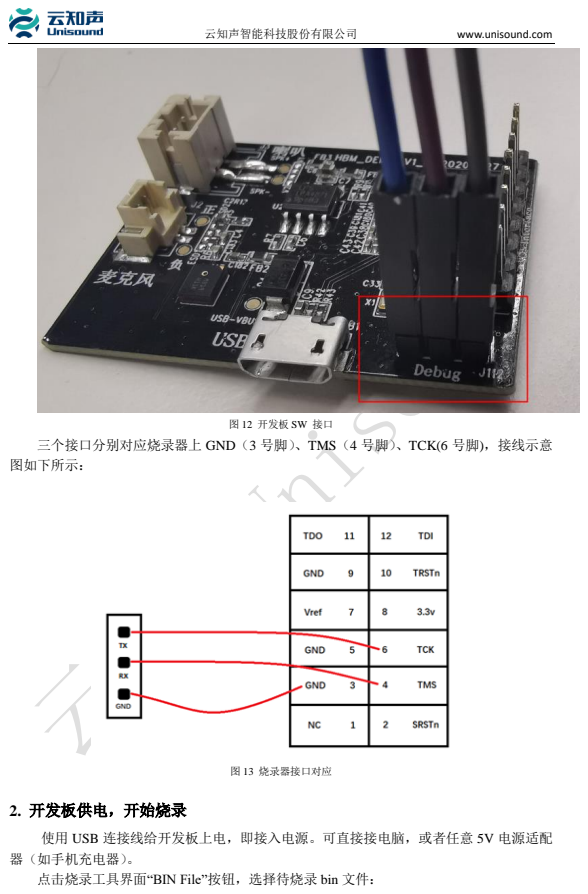
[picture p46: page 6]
图 13 烧录器接口对应; 2. 开发板供电，开始烧录

图 12 开发板 SW 接口

三个接口分别对应烧录器上 GND（3 号脚）、TMS（4 号脚）、TCK(6 号脚)，接线示意
图如下所示：

使用 USB 连接线给开发板上电，即接入电源。可直接接电脑，或者任意 5V 电源适配
器（如手机充电器）。
点击烧录工具界面“BIN File”按钮，选择待烧录 bin 文件：

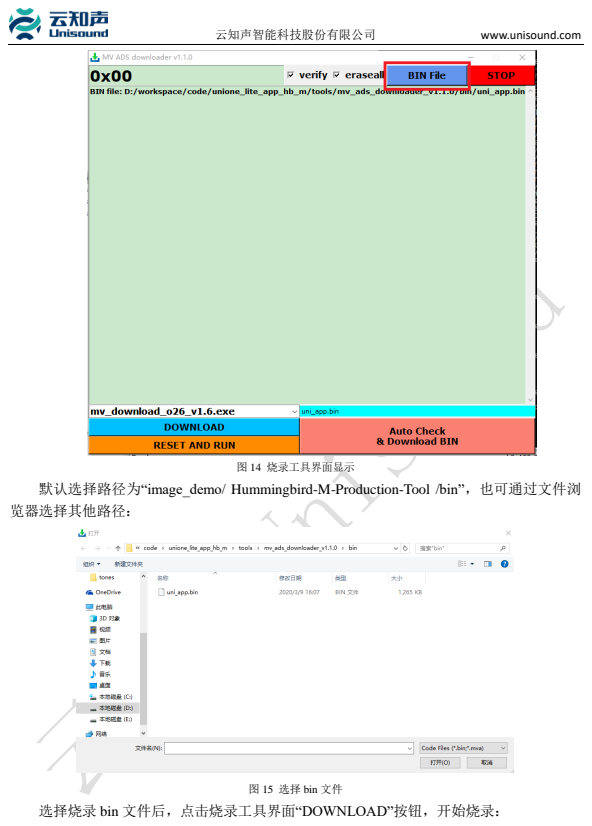
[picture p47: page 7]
图 14 烧录工具界面显示

默认选择路径为“image_demo/ Hummingbird-M-Production-Tool /bin”，也可通过文件浏
览器选择其他路径：

图 15 选择 bin 文件

选择烧录 bin 文件后，点击烧录工具界面“DOWNLOAD”按钮，开始烧录：

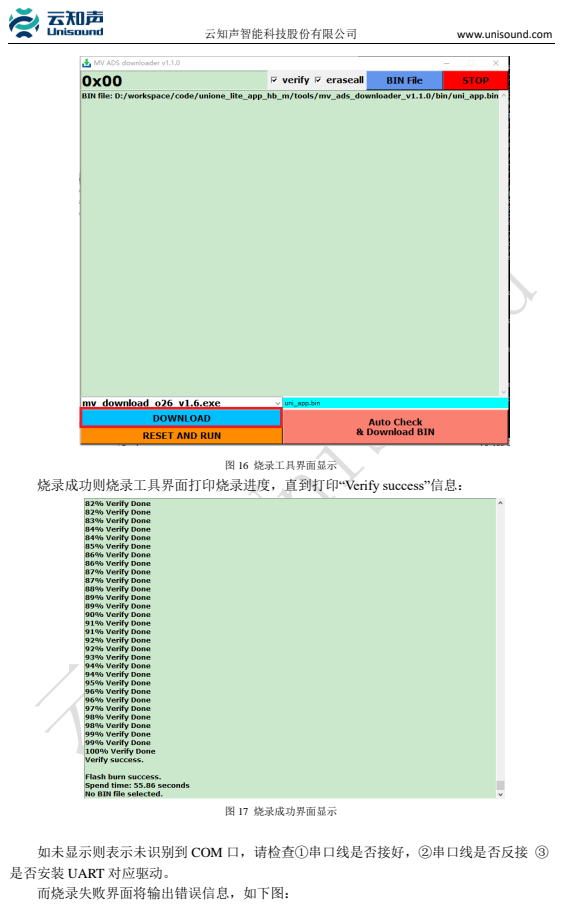
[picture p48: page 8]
图 16 烧录工具界面显示; 图 17 烧录成功界面显示

烧录成功则烧录工具界面打印烧录进度，直到打印“Verify success”信息：

如未显示则表示未识别到 COM 口，请检查①串口线是否接好，②串口线是否反接 ③
是否安装 UART 对应驱动。
而烧录失败界面将输出错误信息，如下图：

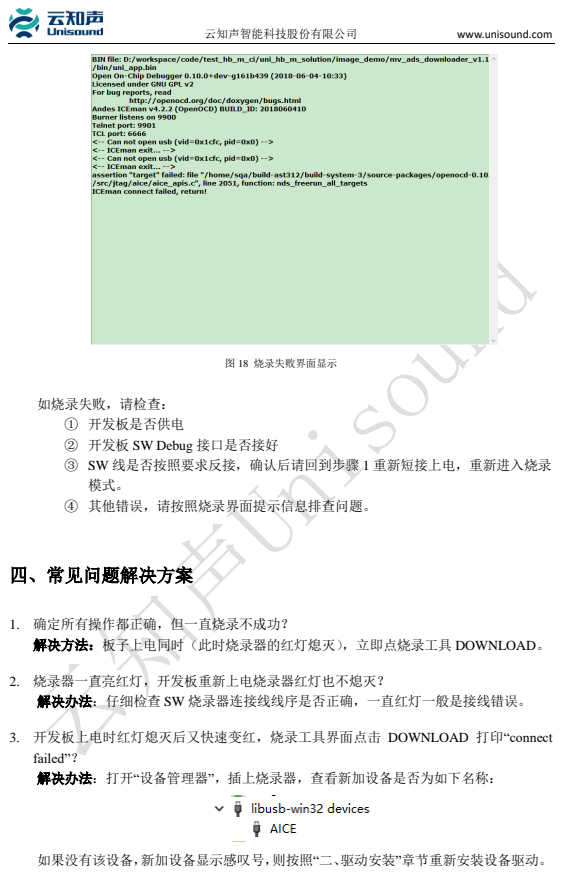
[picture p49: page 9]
图 18 烧录失败界面显示; 四、常见问题解决方案

如烧录失败，请检查：
① 开发板是否供电
② 开发板 SW Debug 接口是否接好
③ SW 线是否按照要求反接，确认后请回到步骤 1 重新短接上电，重新进入烧录
④ 其他错误，请按照烧录界面提示信息排查问题。

1. 确定所有操作都正确，但一直烧录不成功？
解决方法：板子上电同时（此时烧录器的红灯熄灭），立即点烧录工具 DOWNLOAD。

2. 烧录器一直亮红灯，开发板重新上电烧录器红灯也不熄灭？
解决办法：仔细检查 SW 烧录器连接线线序是否正确，一直红灯一般是接线错误。

3. 开发板上电时红灯熄灭后又快速变红，烧录工具界面点击 DOWNLOAD 打印“connect
failed”？
解决办法：打开“设备管理器”，插上烧录器，查看新加设备是否为如下名称：

如果没有该设备，新加设备显示感叹号，则按照“二、驱动安装”章节重新安装设备驱动。

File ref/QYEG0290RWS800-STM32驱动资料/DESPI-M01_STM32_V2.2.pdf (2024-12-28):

# 104 NRST

# PA3/ADC123_IN3/USART2_Rx/T5C4/T2C4 26 VSS_4 27 VDD_4 28

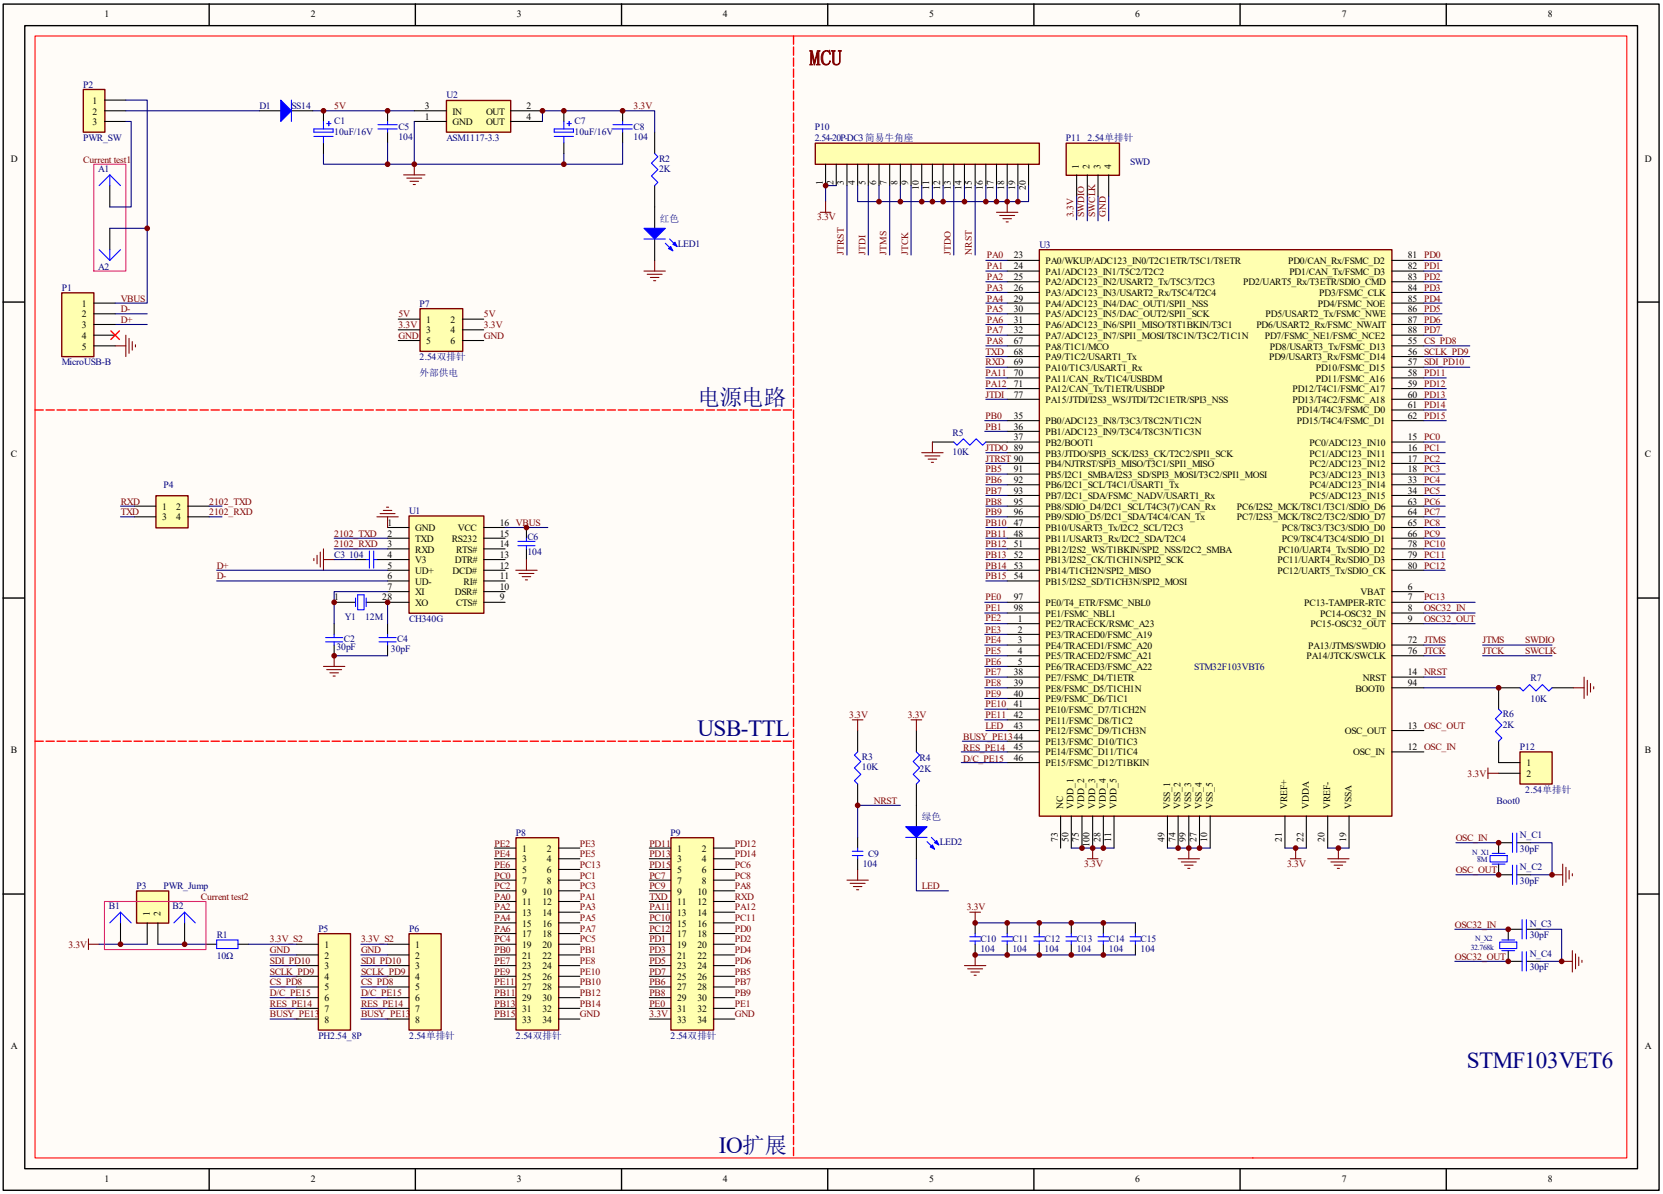
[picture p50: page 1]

SWD 3.3V SWDIO SWCLK GND

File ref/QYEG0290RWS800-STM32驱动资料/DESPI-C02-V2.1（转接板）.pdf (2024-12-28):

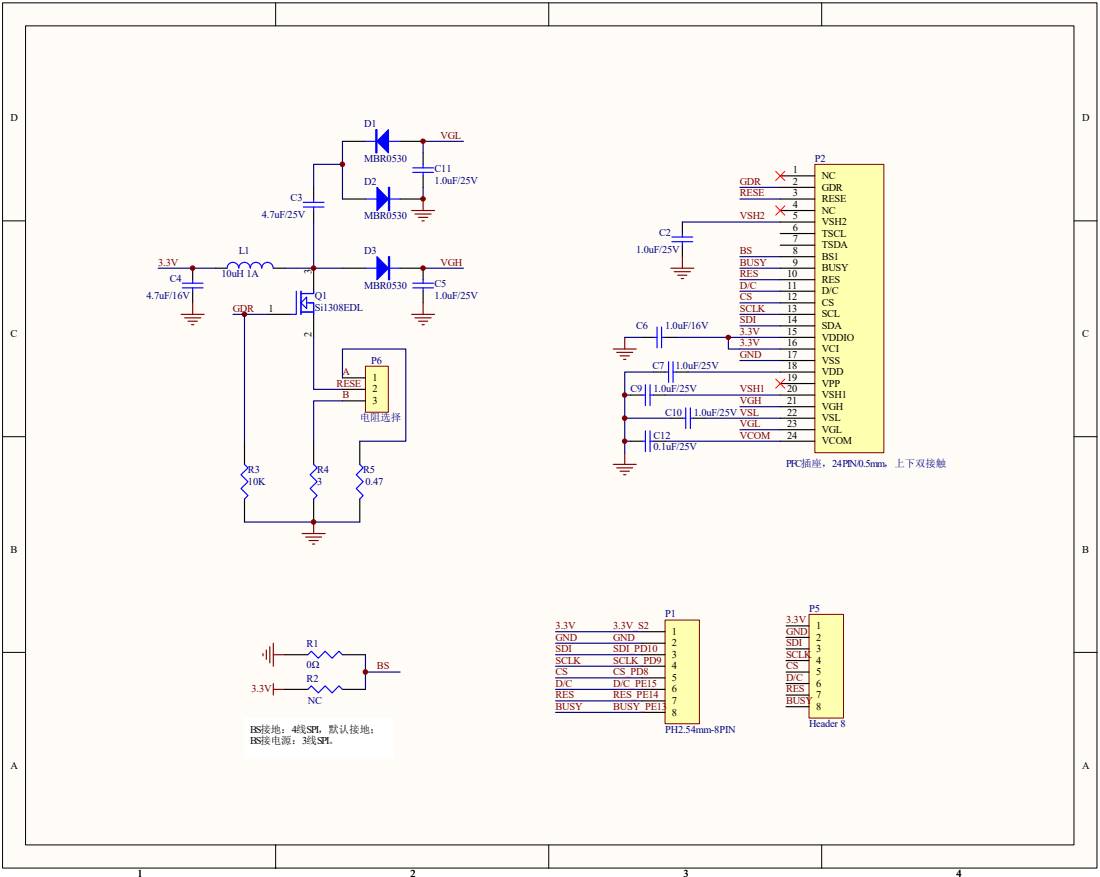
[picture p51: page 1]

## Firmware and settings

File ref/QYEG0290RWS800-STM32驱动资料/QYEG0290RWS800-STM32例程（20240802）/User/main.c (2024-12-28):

#include "stm32f10x.h"
#include "epaper.h" 
#include "picture.h"
ErrorStatus HSEStartUpStatus;

/* Private function prototypes -----------------------------------------------*/
void RCC_Configuration(void);
void NVIC_Configuration(void);
void GPIO_Configuration(void);

/************************************************
************************************************/


						

/////////////////////main//////////////////////////////////////
int main(void)
{

	#ifdef DEBUG
	  debug();
	#endif
	RCC_Configuration();
	//GPIO setting
	GPIO_Configuration();
	 
	  //全屏刷新（横屏显示，FPC朝左）
	  //Full screen refresh
	
		EPD_HW_Init(Hor); //Electronic paper initialization
		EPD_ALL_image(gImage1_BW,gImage1_RED);	//Refresh the picture in full screen
    driver_delay_xms(2000);		
	
		EPD_HW_Init(Hor); 													//Electronic paper initialization（横屏初始化）
	 	EPD_ALL_image(gImage2_BW,gImage2_RED); 	//Refresh the picture in full screen
    driver_delay_xms(2000);		
	
		EPD_HW_Init(Hor); 											//Electronic paper initialization
	 	EPD_SetRAMValue_BaseMap(basemap_BW,basemap_RED); 	//刷新局刷背景，注意此处函数不一样
    driver_delay_xms(1500);			

//////////////////////Partial refresh digital presentation///////////////////
///////////////////////////////////////////局刷
//0613

//注意：单个图片刷新的时候，数据发送完直接执行 EPD_Part_Update();
//      多个图标一起刷新的时候，所有数据全都发送完毕，一次性执行 EPD_Part_Update();
//      y和显示高度必须是8的整数倍。
		
		EPD_HW_Init(Hor); 													//Electronic paper initialization（初始化）
		EPD_multiple_Part(x_digit_1,y_digit,Num[0],Num[6],Num[1],Num[3]); 					
		EPD_Part_Update_And_DeepSleep();
    driver_delay_xms(1500);		


///////////////////////////////////////////
//2748

//采用局刷方式连续刷新多个显示界面的时候，从休眠状态唤醒只需要硬件复位就可以，不要重新初始化。

		EPD_W21_Init();						//hard reset
		EPD_multiple_Part(x_digit_1,y_digit,Num[2],Num[7],Num[4],Num[8]); 		
		EPD_Part_Update_And_DeepSleep();
    driver_delay_xms(1500);		
		
		
//////////////////////////////////////////
//1905

		EPD_W21_Init();						//hard reset
		EPD_multiple_Part(x_digit_1,y_digit,Num[1],Num[9],Num[0],Num[5]); 	
		EPD_Part_Update_And_DeepSleep();
    driver_delay_xms(1500);		


	  //全刷（竖屏）刷新整张图片
		EPD_HW_Init(Ver);  													//Electronic paper initialization（竖屏初始化）	
	 	EPD_ALL_image(gImage3_BW,gImage3_RED); 	//Refresh the picture in full screen
    driver_delay_xms(2000);	


////////////////////////////////////////////////////////////////////////	
		//Clear screen
	
		EPD_HW_Init(Ver); //Electronic paper initialization			
		EPD_WhiteScreen_White();  //Show all white
    driver_delay_xms(1000);			

		EPD_HW_Init(Ver); //Electronic paper initialization			
		EPD_WhiteScreen_White();  //Show all white
}
///////////////////////////////////////////////////////////





/*******************************************************************************
* Function Name  : RCC_Configuration
* Description    : Configures the different system clocks.
* Input          : None
* Output         : None
* Return         : None
*******************************************************************************/
void RCC_Configuration(void)
{
 
  // Reset RCC clock configuration
  RCC_DeInit();
 
  // Enable external crystal
  RCC_HSEConfig(RCC_HSE_ON);
  
  // Waiting for the external crystal to stabilize
  HSEStartUpStatus = RCC_WaitForHSEStartUp();
  if(HSEStartUpStatus == SUCCESS)
  {
    // Set the phase-locked loop frequency PLLCLK = 8MHz * 9 = 72 MHz
    RCC_PLLConfig(RCC_PLLSource_HSE_Div1, RCC_PLLMul_9);
  }
  else {
    // Enable internal crystal
    RCC_HSICmd(ENABLE);
    // Waiting for the internal crystal to stabilize
    while(RCC_GetFlagStatus(RCC_FLAG_HSIRDY) == RESET);

    // Set the phase-locked loop frequency PLLCLK = 8MHz/2 * 16 = 64 MHz 
    RCC_PLLConfig(RCC_PLLSource_HSI_Div2,RCC_PLLMul_16);
  }

    // Enable flash prefetch cache
  FLASH_PrefetchBufferCmd(FLASH_PrefetchBuffer_Enable);

  //Set the code delay, FLASH_Latency_2 is two delay cycles
  FLASH_SetLatency(FLASH_Latency_2);
	
  //Set the system total clock
  RCC_HCLKConfig(RCC_SYSCLK_Div1); 

  //Set the high speed device total clock, RCC_HCLK_Div1 is the system clock divided by 1
  RCC_PCLK2Config(RCC_HCLK_Div1); 

  //Set the low speed device total clock, RCC_HCLK_Div2 is the system clock divided by 2
  RCC_PCLK1Config(RCC_HCLK_Div2);
  
  //Enable phase-locked loop multiplier
  RCC_PLLCmd(ENABLE);
  
  // Waiting for the frequency of the phase-locked loop to multiply after frequency stabilization
  while(RCC_GetFlagStatus(RCC_FLAG_PLLRDY) == RESET);
  
  // Select the phase-locked loop clock as the system clock
  RCC_SYSCLKConfig(RCC_SYSCLKSource_PLLCLK);
  
  // Waiting for setup to complete
  while(RCC_GetSYSCLKSource() != 0x08);
    
  RCC_APB2PeriphClockCmd(RCC_APB2Periph_GPIOA |
            RCC_APB2Periph_USART1|RCC_APB2Periph_AFIO,
            ENABLE);

}

/*******************************************************************************
* Function Name  :  GPIO_Configuration
* Description    : Configures the different system clocks.
* Input          : None
* Output         : None
* Return         : None
*******************************************************************************/
void GPIO_Configuration(void)
{
	GPIO_InitTypeDef  GPIO_InitStructure;
 	
	RCC_APB2PeriphClockCmd(RCC_APB2Periph_GPIOD|RCC_APB2Periph_GPIOE, ENABLE);//使能PD、E端口时钟
	  				     	
	
	 //CS-->PD8   SCK-->PD9  SDO--->PD10 
	GPIO_InitStructure.GPIO_Pin = GPIO_Pin_8|GPIO_Pin_9|GPIO_Pin_10;		//Port configuration
	GPIO_InitStructure.GPIO_Mode = GPIO_Mode_Out_PP; 		 			
	GPIO_InitStructure.GPIO_Speed = GPIO_Speed_2MHz;		 		
	GPIO_Init(GPIOD, &GPIO_InitStructure);	  	
	
	
	
	 // D/C--->PE15	   RES-->PE14
	GPIO_InitStructure.GPIO_Pin = GPIO_Pin_14|GPIO_Pin_15;		//Port configuration
	GPIO_InitStructure.GPIO_Mode = GPIO_Mode_Out_PP; 		 			
	GPIO_InitStructure.GPIO_Speed = GPIO_Speed_2MHz;		 		
	GPIO_Init(GPIOE, &GPIO_InitStructure);	  				     		
	
	// BUSY--->PE13
	GPIO_InitStructure.GPIO_Pin  = GPIO_Pin_13;
	GPIO_InitStructure.GPIO_Mode = GPIO_Mode_IN_FLOATING; //Floating input
	GPIO_InitStructure.GPIO_Speed = GPIO_Speed_2MHz;
  GPIO_Init(GPIOE, &GPIO_InitStructure);    //Initialize GPIO
	
	 //LED
	GPIO_InitStructure.GPIO_Pin = GPIO_Pin_12;		//Port configuration
	GPIO_InitStructure.GPIO_Mode = GPIO_Mode_Out_PP; 		 			
	GPIO_InitStructure.GPIO_Speed = GPIO_Speed_2MHz;		 		
	GPIO_Init(GPIOE, &GPIO_InitStructure);
}

/*******************************************************************************
* Function Name  : NVIC_Configuration
* Description    : Configures Vector Table base location.
* Input          : None
* Output         : None
* Return         : None
*******************************************************************************/
void NVIC_Configuration(void)
{ 
  //NVIC_InitTypeDef NVIC_InitStructure;
  ;
}


#ifdef  DEBUG
/*******************************************************************************
* Function Name  : assert_failed
* Description    : Reports the name of the source file and the source line number
*                  where the assert_param error has occurred.
* Input          : - file: pointer to the source file name
*                  - line: assert_param error line source number
* Output         : None
* Return         : None
*******************************************************************************/
void assert_failed(u8* file, u32 line)
{ 
  /* User can add his own implementation to report the file name and line number,
     ex: printf("Wrong parameters value: file %s on line %d\r\n", file, line) */

  /* Infinite loop */
  while (1)
  {
  }
}
#endif

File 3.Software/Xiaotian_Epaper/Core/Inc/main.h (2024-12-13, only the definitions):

#define DS1302_CE_Pin GPIO_PIN_13
#define DS1302_CE_GPIO_Port GPIOC
#define IO_LED_Pin GPIO_PIN_1
#define IO_LED_GPIO_Port GPIOA
#define EP_SDI_Pin GPIO_PIN_4
#define EP_SDI_GPIO_Port GPIOA
#define EP_SCK_Pin GPIO_PIN_5
#define EP_SCK_GPIO_Port GPIOA
#define EP_CS_Pin GPIO_PIN_6
#define EP_CS_GPIO_Port GPIOA
#define EP_DC_Pin GPIO_PIN_7
#define EP_DC_GPIO_Port GPIOA
#define EP_RST_Pin GPIO_PIN_0
#define EP_RST_GPIO_Port GPIOB
#define EP_BUSY_Pin GPIO_PIN_1
#define EP_BUSY_GPIO_Port GPIOB
#define DS1302_SCL_Pin GPIO_PIN_8
#define DS1302_SCL_GPIO_Port GPIOB
#define DS1302_DATA_Pin GPIO_PIN_9
#define DS1302_DATA_GPIO_Port GPIOB

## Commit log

2024-12-13 添加了readme
    添加了readme
2024-12-13 添加文件
    [M2-10mm.SLDPRT, M3-10mm.SLDPRT, M3-6mm.SLDPRT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]
2024-12-13 上传代码和硬件项目链接
2024-12-13 一点修改
2024-12-13 更新图片
2024-12-14 software更新
2024-12-14 更新电路设计
2024-12-24 update 软件
2024-12-28 添加黑白红显示
2025-01-05 编译更新
    [盖子.3mf]
2025-01-05 完善更新
    [BOM清单2024-12-14.xlsx]
2025-01-05 更新了一点小bug
2025-01-18 更新红黑墨水屏适配
2025-01-18 更新readme
    [BOM清单2024-12-14.xlsx]
2025-02-09 更新二次开发教程
2025-02-11 添加自动更新时间功能
2025-03-26 添加无内嵌螺母版本的外壳文件
    [外壳1 - 无内嵌螺母版本.SLDPRT, 外壳1 - 无内嵌螺母版本.STL, 盖子.3mf]
2025-04-13 优化更新
    添加scene3红黑显示demo，为”时间时加一“添加边界限制；更新了3D结构文件，删除了需要内嵌螺母的我外壳版本；pcb完善了丝印；
    [m2螺母.SLDPRT, 外壳1 - 无内嵌螺母版本.SLDPRT, 外壳1 - 无内嵌螺母版本.STL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]
2025-04-13 删除多余的图片
2025-04-13 加入视频链接
2025-05-10 更新串口打印内容
2025-05-16 解决一些bug
    解决了偶然出现的秒计时超出60导致计时停止问题，优化了时间自动更新（若编译时间超前当前时间或当前时间大于编译时间20年则更新为编译时间）
2025-05-18 完善功能
    完善按照编译时间自动更新时间的功能
2025-07-19 完善bom清单
    [BOM清单2024-12-14.xlsx, 外壳1.STL, 小天-外壳.STL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]

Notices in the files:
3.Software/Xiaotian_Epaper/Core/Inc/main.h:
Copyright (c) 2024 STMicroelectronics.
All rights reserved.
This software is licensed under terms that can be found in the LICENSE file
